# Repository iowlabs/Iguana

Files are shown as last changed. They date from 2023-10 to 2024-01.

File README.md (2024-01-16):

# iow Labs Iguana

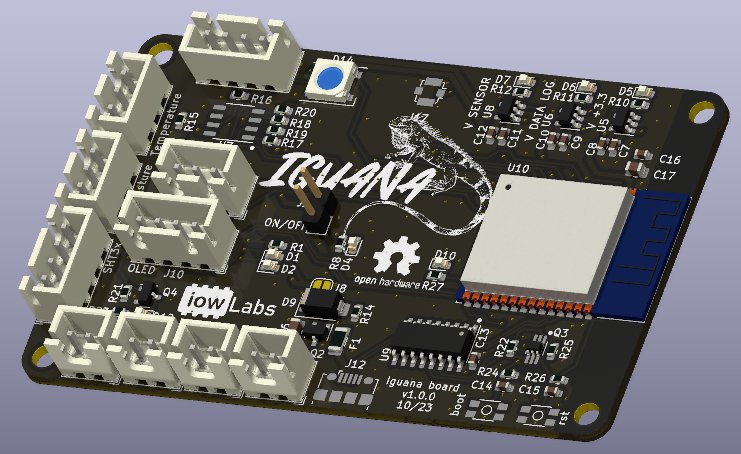
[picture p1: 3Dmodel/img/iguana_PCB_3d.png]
Foto real


Iguana is a LoRa sensor for Smart Cities. It is an instrument designed to monitor soil temperature and humidity in real time. It is a low-cost device designed to address a wide range of scenarios. It has connectivity to different types of wireless networks (LoRa, Bt, BLE, Wifi, RF), adapting to a large number of IoT applications.

The PCB was designed with various scenarios in mind that contemplate the common needs associated with automatic irrigation, smart agriculture and soil quality monitoring. Both at the level of domestic applications and at the level of industrial applications.

The sensor considers compatibility with the following sensors:

- Soil moisture sensor ds18b20
- soil temperature sensor.
- Humidity and ambient temperature sensor.

It also has a  on board driver for a little water pump, a LoRa module, an RTC module and an SD socket for datalogger functions and an OLED screen to display instant information. Another interesting attribute is that it has an RS485 converter, which allows the iguana device to be integrated with industrial sensors for monitoring soil humidity and quality that are usually compatible with ModBus RS485 protocols.

**IoT**,**LoRa**, **Environmental measurement**, **Soil mositure**, **datalogger**, **MODBUS RS485**.

### OSHW LICENSES

 OSL  

## Hardware description

The PCB was designed in KiCad7 stable realease and additional components used can be found in the official [iowLabs](https://github.com/iowlabs/KiCad_Lib) library.

It has an ESP32 microcontroller, an RF95 module to integrate into LoRa and LoRaWAN network solutions. It has an RTC RV8803 and a micro SD card connector necessary to implement data logger functions.
It additionally has a "max485" module to integrate probes for quality monitoring of industrial soils based on MODBUS RS485 communication protocol.

A simple NPN-based controller allows you to integrate small water pumps to implement automatic and remote irrigation control functionalities.

An OLED display and RGB LED let you see real-time information from the sensors.

It also has a charging module for lipo batteries based on the integrated TP4056 and a charging protection circuit. Integration with solar panel based applications can be easily achieved.

To manage the power of the circuit, an MT3608 DC DC converter and a set of LDO regulators are used that power the digital electronics, the sensors and the data logger independently. The regulators that power the units can be disabled via firmware to implement low-power features.

### Dependencies
The board is based on an ESP32 microcontroller.

- USB communication through IC CH340
- Lora rfm95 module.
- microSD socket.
- RV8803 RTC module.
- max485 for RS485 communication.
- On board pump driver with a NPN 2N3904.
- On board battery charger compatible with 3.7V lipo bateries, based on TP4056.
- ws2812 RGB LED
- OLED display

### Schematic

Detalle del esquemático de la placa phecda

### Layout
The layout is a 2 layers 8x5cm pcb.

| Top view | Bottom view |
| --- | --- |
| front view of the pcb form kicad|back view of the pcb form kicad|

### BOM

The bill of materials with respective references to the LCSC part numbers of the iguana PCB components can be found in the following [link](hardware/output_files/Iguana_V1_BOM.csv).

Below is a list of the components for the probes and sensors that complement the iguana device to implement all its functionalities. The prices provided and the links are for reference only.

|  component 	| ref price 	| description 	| Link 		|
| --- 	| --- 	| --- | ---	|
| Soil mositure sensor| | 	Low cost, soil moisture capacitive sensor	|			|
| Soil temperature sensor | | Sensor ds18b20 | |
| Sensor de humedad y temperatura ambiente | | SHT31 - case outdoor IP68 | |
| Sensor de Temperatura y humedad de suelo industrial | | Sensor MODBUS 485 capacitivo, de humedad y temperatura de suelo. | |
| Pantalla OLED |  | 128x64 1.3'' | |
| Batería LiPo  |  | Batería lipo 3.7V 2500mAh.Tamaño menor a 65x55cm.  | |
| Tarjeta microSD | | 16GB | |
| Batería 2012 	| | Batería 3.3V CR2012 | |

## 3D Model

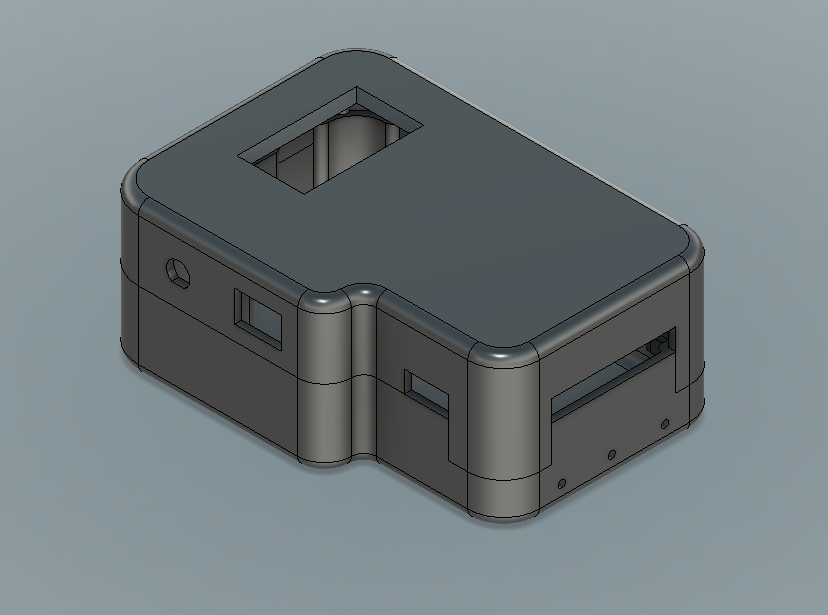
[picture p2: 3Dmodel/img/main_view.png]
Enclousure diseñado para Iguana


Render 3D de la placa Iguana

The design allows the integration of the OLED and RGB LED display to monitor the status of the device and read the latest value from the sensors. it leaves exposed the connectors for the probes, the SMA connector for the LoRa antenna, and a switch to turn the device on and off.

| Cover | Base |
| --- | --- |
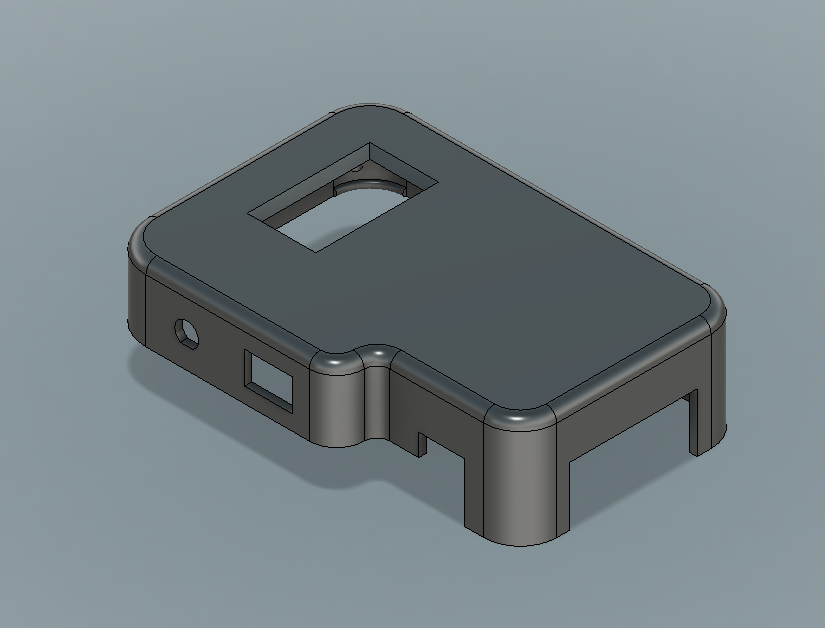
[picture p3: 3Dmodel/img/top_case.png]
componente superior del case
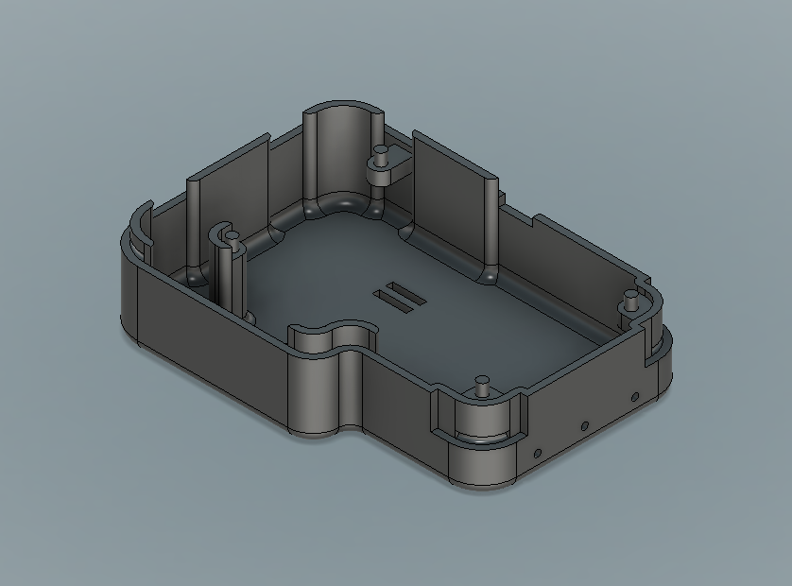
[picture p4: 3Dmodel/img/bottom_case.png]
componente inferior del case
| ||

Design view files:

- [plans](Iguna_case_V2.pdf)

The device considers a 65x54 cm 3.7V lipo battery for power. This battery can be charged externally through the USB connector or through the charging input connector.

Editable files and display plans can be found in [directorio](3Dmodel/Source_files).

The PCB design allows it to fit commercial project enclosures with IP65 standards or higher for outdoor or harsh weather applications.

## Firmware

The developed firmware represents a collection of libraries and drivers for the board's dependencies.

This collection of useful functions is implemented in the iowIguana library. However, due to the flexibility of the design, it is possible to load a wide variety of code based on other supported libraries.

The firmware was developed using PlatformIO; however, usage examples were generated for [Arduino IDE] (https://www.arduino.cc/en/software).

|  Folder  | Description |
| ---| --- |
| [firmware/iguana_project](firmware/iguana_project) | The complete project compiled in its last version.|
| [firmware/examples](firmware/examples) | Arduino compatible example codes .|
| [firmware/src](firmware/src) | The source files of the library made for iguana.|

### Used libraries
Except for the uSD_iow library which is available in the official iowlabs repository, all other libraries used are available from the official Arduino and PlatformIO library manager.

- RTC 			: sparkfun/SparkFun Qwiic RTC RV8803 Arduino Library @ ^1.2.8
- Temperature sensor	: paulstoffregen/OneWire@^2.3.7
- Temperature sensor 	: milesburton/DallasTemperature@^3.11.0
- Temperature and humidity sensor : adafruit/Adafruit SHT31 Library@^2.2.2
- Temperature and humidity sensor : adafruit/Adafruit BusIO@^1.14.3
- Temperature and humidity sensor : adafruit/Adafruit Unified Sensor@^1.1.13
- ArduinoJson	:	bblanchon/ArduinoJson@^6.21.3
- OLED			: adafruit/Adafruit SH110X @ ^2.1.8
- OLED 			: adafruit/Adafruit GFX Library @ ^1.11.5
- fastLED		: fastled/FastLED@^3.6.0
- LoRa 			: sandeepmistry/LoRa @ ^0.8.0
- MQTT               : knolleary/PubSubClient@^2.8

### Available examples

| File | Description |
|---|---|
| simple_version.ino  | Collect the data from the soil moisture and the soil temperature sensors, and displays it on the screen. Print the collected data in json format through the serial monitor. |
| low_energy_version.ino |  Adds a low-power mode to the simple_version code |
| lora_version.ino | Activate the LoRa module and send a message in json format. |
| mqtt_version.ino | This is an example of reading the data and sending it via MQTT to a pre-established broker.|

### Available functions

- uint8_t begin(void);
- void readSoilTemperature(void);
- void readSoilMoisture(void);
- void readSTH(void);
- void readRS485(void);
- void readSensors(void);
- String pubData(void);
- void activateSensors(uint8_t sens);
- void activateLoRa(void);
- void activateAll(void);
- void iowLogo(void);
- void showLogo(void);
- void showStatus(void);
- void showData(long time_interval);
- void saveData(void);
- void moistureCal(uint8_t val);
- void temperatureCal(uint8_t val);

## OTA UPDATE Disclaimer
- Iguana ahora es capaz de tener actualizaciones Http mediante OTA
- En la carpeta test se encuentra el archivo "OTA_update_mqtt.cpp"
- Robusto ante corte de energía durante actualización
- Existía un bug cuando se cortaba el wifi del dispositivo en medio de una actualización. Se levantaba un error de la librería WiFiClientSecurity en el archivo ssl_client.cpp
- Solución a bug: Se modifica el archivo ssl_client.cpp de forma que a penas se levante el error (linea 37) se haga ESP.restart(). Con esto OTA es robusto ante cualquier fallo testeado.
- Para que todo se encuentre en el repo, se descargaron los archivos .cpp y .h de la librería WiFiClientSecurity y se cargaron en la carpeta libs del proyecto. Esto con el fin de que el arreglo lo pueda pullear cualquiera que tome este código.

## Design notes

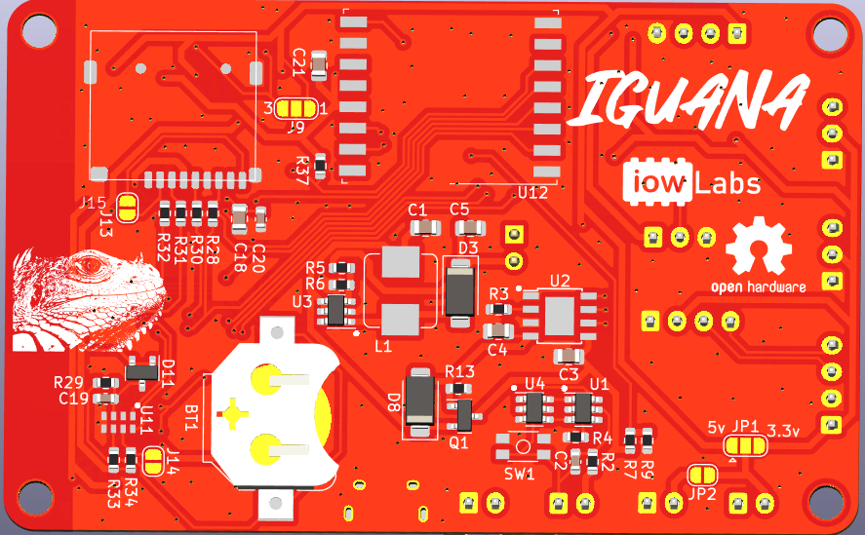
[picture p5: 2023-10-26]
hardware/output_files/Iguana_V1_botom.png

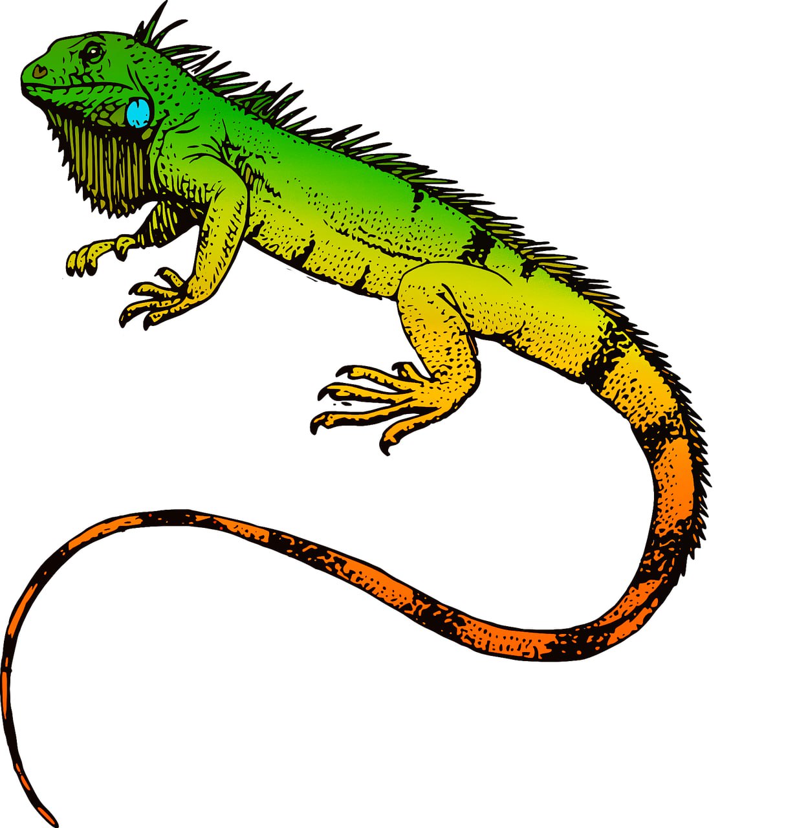
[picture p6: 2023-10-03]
hardware/fotos/photo_iguana_free.jpg

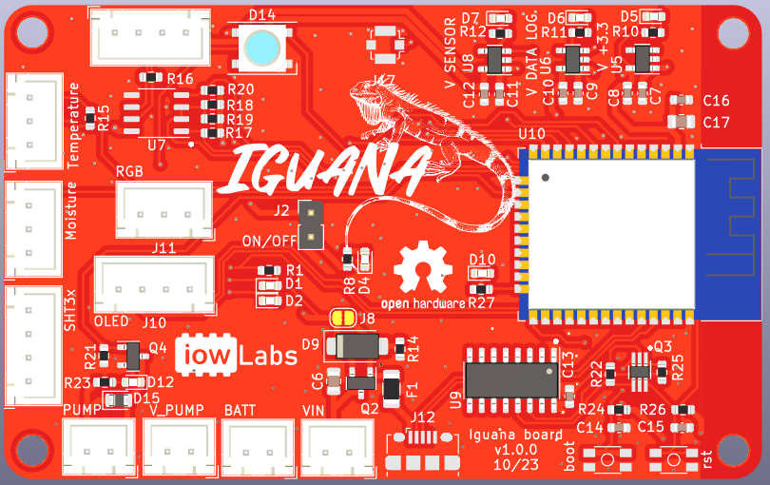
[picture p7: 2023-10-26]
hardware/output_files/Iguana_V1_top.png

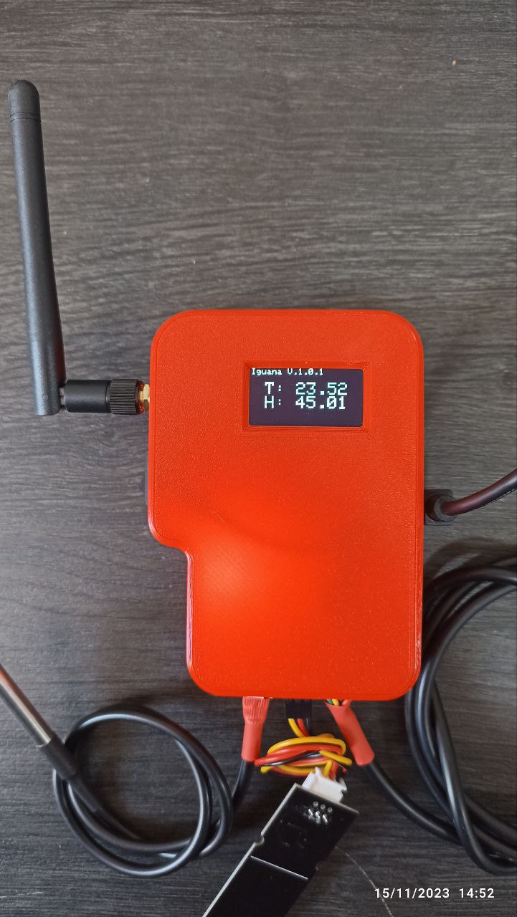
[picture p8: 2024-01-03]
3Dmodel/img/iguana_real.jpg

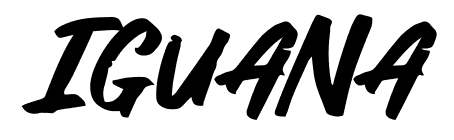
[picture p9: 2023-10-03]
hardware/fotos/logo.png

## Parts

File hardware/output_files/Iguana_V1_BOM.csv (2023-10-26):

Item | Reference(s) | Qty | Value | Footprint | Supplier | Supplier part number
Battery holder | BT1 | 1 | Battery_Cell | Battery:BatteryHolder_Keystone_3000_1x12mm | LCSC | C964819
CAP ceramic | C1, C5 | 2 | 22u | Capacitor_SMD:C_0805_2012Metric | LCSC
CAP ceramic | C2, C13, C14, C15, C16, C20 | 6 | 100n | Capacitor_SMD:C_0603_1608Metric | LCSC | C1591
CAP ceramic | C3, C4, C17, C18 | 4 | 10u | Capacitor_SMD:C_0805_2012Metric | LCSC | C386019
CAP ceramic | C6, C21 | 2 | 4.7u | Capacitor_SMD:C_0805_2012Metric | LCSC | C98192
CAP ceramic | C7, C8, C9, C10, C11, C12 | 6 | 1u | Capacitor_SMD:C_0603_1608Metric | LCSC | C5673
CAP ceramic | C19 | 1 | 10n | Capacitor_SMD:C_0603_1608Metric | LCSC | C100042
LED SMD BLUE 0603 |  |  |  | LED_SMD:LED_0603_1608Metric | LCSC
LED SMD BLUE 0603 |  |  |  | LED_SMD:LED_0603_1608Metric | LCSC
LED SMD BLUE 0603 | D1, D2, D4, D5, D6, D7, D10, D12 | 8 |  | LED_SMD:LED_0603_1608Metric | LCSC | C99290
Diode schottky | D3, D8, D9 | 3 |  | Diode_SMD:D_SMA | LCSC | C85098
Diode BAS70-05 | D11 | 1 |  | Package_TO_SOT_SMD:SOT-23 | LCSC | C131857
RGB SMD LED WS2812B | D14 | 1 |  | LED_SMD:LED_WS2812B_PLCC4_5.0x5.0mm_P3.2mm | LCSC
Generic diode CD4148W | D15 | 1 |  | Diode_SMD:D_0805_2012Metric | LCSC
Fuse | F1 | 1 |  | Fuse:Fuse_1206_3216Metric | LCSC | C553921
Header male 2x1 p2.54 | J2 | 1 |  | Connector_PinHeader_2.54mm:PinHeader_1x02_P2.54mm_Vertical | LCSC | C180247
Connector JST XH 2x1 p2.5 | J1,J3, J18, J19 | 4 |  | Connector_JST:JST_XH_B2B-XH-A_1x02_P2.50mm_Vertical | LCSC
Connector JST XH 3x1 p2.5 | J4,J5,J11 | 3 |  | Connector_JST:JST_XH_B3B-XH-A_1x03_P2.50mm_Vertical | LCSC
Connector JST XH 4x1 p2.5 | J6,J7,J10 | 1 |  | Connector_JST:JST_XH_B4B-XH-A_1x04_P2.50mm_Vertical | LCSC | C37815
Solder Jumper | J8,J13,JP1 | 3 |  | Jumper:SolderJumper-2_P1.3mm_Open_RoundedPad1.0x1.5mm
Solder Jumper | J9,J14,JP2 | 3 |  | Jumper:SolderJumper-3_P1.3mm_Open_RoundedPad1.0x1.5mm_NumberLabels
USB micro b | J12 | 1 |  | Connector_USB:USB_Micro-B_Amphenol_10118194_Horizontal | LCSC | C132563
Micro SD holder push push | J15 | 1 |  | IoWLabsConnectors:microSD_push_push | LCSC
Connector UFL SMD | J17 | 1 |  | Connector_Coaxial:U.FL_Molex_MCRF_73412-0110_Vertical | LCSC | C88374
Inductance SMD | L1 | 1 | 22u | Inductor_SMD:L_Bourns_SRP7028A_7.3x6.6mm | LCSC
PMOS transistor | Q1, Q2 | 2 |  | Package_TO_SOT_SMD:SOT-23 | LCSC | C518789
LMBT3904 Dual NPN transistor | Q3 | 1 |  | Package_TO_SOT_SMD:SOT-363_SC-70-6_Handsoldering | LCSC | C131781
PMOS transistor BSS138 | Q4 | 1 |  | Package_TO_SOT_SMD:SOT-23 | LCSC | C400505
RES SMD | R1, R10, R11, R12, R23,R4, R6 | 7 | 1k | Resistor_SMD:R_0603_1608Metric | LCSC
RES SMD | R2 | 1 | 100 | Resistor_SMD:R_0603_1608Metric | LCSC
RES SMD | R3 | 1 | 1K2 | Resistor_SMD:R_0603_1608Metric | LCSC
RES SMD | R5 | 1 | 7K5 | Resistor_SMD:R_0603_1608Metric | LCSC
RES SMD | R7 | 1 | 12K | Resistor_SMD:R_0603_1608Metric | LCSC
RES SMD | R8 | 1 | 470 | Resistor_SMD:R_0603_1608Metric | LCSC
RES SMD | R9 | 1 | 30K | Resistor_SMD:R_0603_1608Metric | LCSC
RES SMD | R15 | 1 | 4.7K | Resistor_SMD:R_0603_1608Metric | LCSC | C99782
RES SMD | R16 | 1 | 120 | Resistor_SMD:R_0603_1608Metric | LCSC
RES SMD | R17, R18, R19, R20, R37,R13, R14, R22, R24, R25, R26,21 | 12 | 10k | Resistor_SMD:R_0603_1608Metric | LCSC | C25804
RES SMD | R27 | 1 | 330 | Resistor_SMD:R_0603_1608Metric | LCSC | C105881
RES SMD | R28, R29, R30, R31, R32 | 5 | 3.3k | Resistor_SMD:R_0603_1608Metric | LCSC | C25995
RES SMD | R33, R34 | 2 | 100k | Resistor_SMD:R_0603_1608Metric | LCSC | C2907088
Switch button smd | SW1, SW2, SW3 | 3 |  | IoWLabs:SMD_SWITCH | LCSC | C128941
53 | U1 | 1 | DW01 | Package_TO_SOT_SMD:SOT-23-6 | LCSC
54 | U2 | 1 | TP4056 | IoWLabs:TP4056_SOP-8-PP | LCSC
55 | U3 | 1 | MT3608 | Package_TO_SOT_SMD:SOT-23-6 | LCSC
56 | U4 | 1 | FS8205A | Package_TO_SOT_SMD:SOT-23-6 | LCSC
LDO 3.3V AP2112K-3.3 | U5, U6, U8 | 3 |  | Package_TO_SOT_SMD:SOT-23-5 | LCSC | C150742
58 | U7 | 1 | MAX3485 | Package_SO:SOP-8_3.9x4.9mm_P1.27mm | LCSC
CH340 usb to serial | U9 | 1 | CH340C | Package_SO:SOIC-16_3.9x9.9mm_P1.27mm | LCSC | C84681
ESP32 | U10 | 1 |  | RF_Module:ESP32-WROOM-32 | LCSC | C473012
RTC RV-8803 | U11 | 1 | RV-8803 | IoWLabs:SON-8 | LCSC | C2846926
LORA RFM95W-915S2 module 915hz | U12 | 1 | RFM95W-915S2 | RF_Module:HOPERF_RFM69HW | LCSC | C2844473

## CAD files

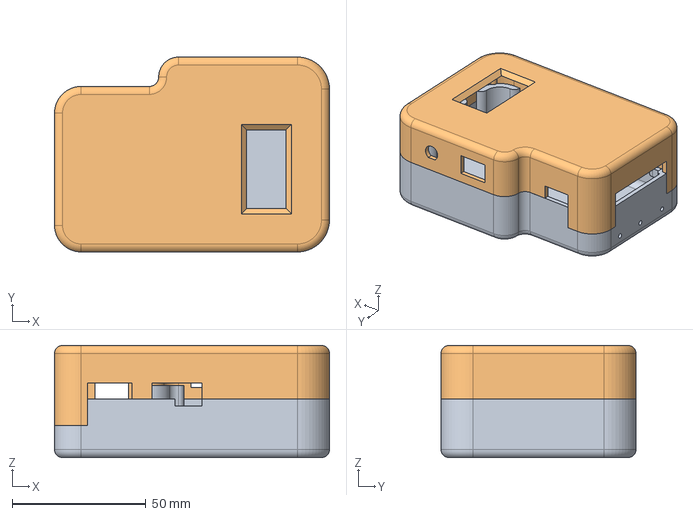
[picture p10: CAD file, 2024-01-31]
3Dmodel/Source_files/V3/Iguana_Case_Final v3.step
103.0 x 73.0 x 42.0 mm

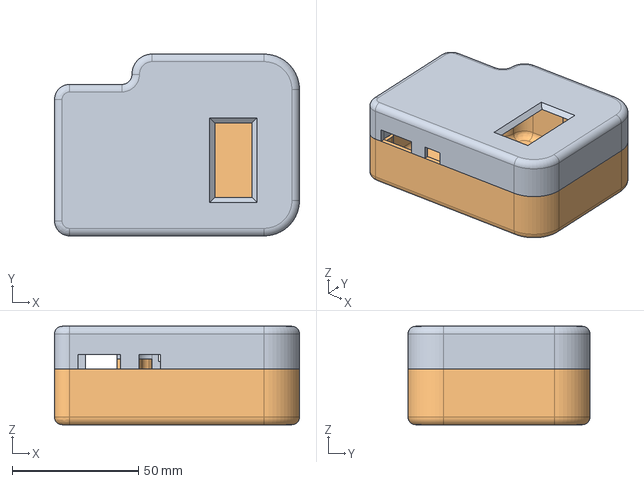
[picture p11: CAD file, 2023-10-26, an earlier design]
3Dmodel/Source_files/V1/Iguana_Case_V1.step
97.0 x 72.0 x 39.0 mm

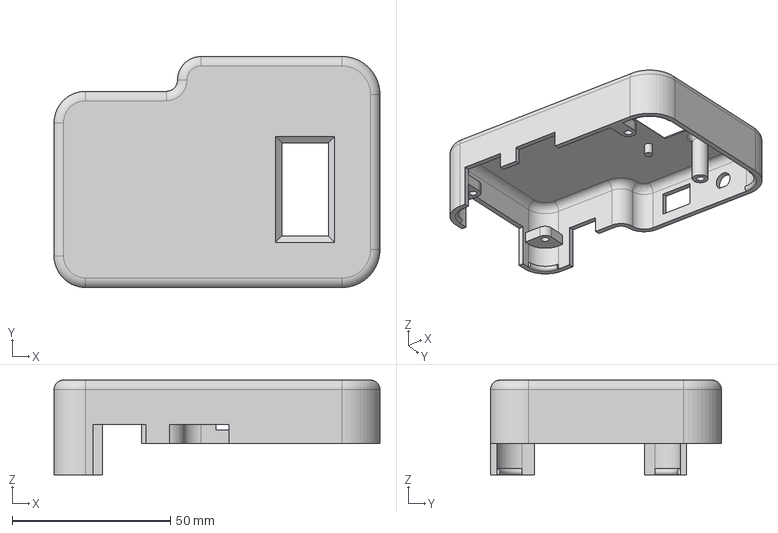
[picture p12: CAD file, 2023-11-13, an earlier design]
3Dmodel/Source_files/V2/Iguana_Case_Final v2.step
103.0 x 73.0 x 30.0 mm

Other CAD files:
3Dmodel/Source_files/V1/Iguana_Case_V1.3mf
3Dmodel/Source_files/V1/Iguana_Case_V1.stl
3Dmodel/Source_files/V2/Iguana_Case_Final v2.f3z
3Dmodel/Source_files/V2/Iguana_Case_Final v2.stl
3Dmodel/Source_files/V3/Iguana_Case_V1.f3z

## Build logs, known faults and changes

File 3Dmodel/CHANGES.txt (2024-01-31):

- V1:
	- Uses magnets, has to be stopped at the 3Dprint
	- Fitting good, dissasembles easy
	- Screen has 1 to 2mm vertical misalignment.

- V2:
	- Discarded magnets, uses tab and slot union, more difficult to close, more realiable.
	- Construction file is simpler, construction was made more efficiently.
	- Screen fits better.

- V3:
	- Increased girth of top tongues, because of structural issue.

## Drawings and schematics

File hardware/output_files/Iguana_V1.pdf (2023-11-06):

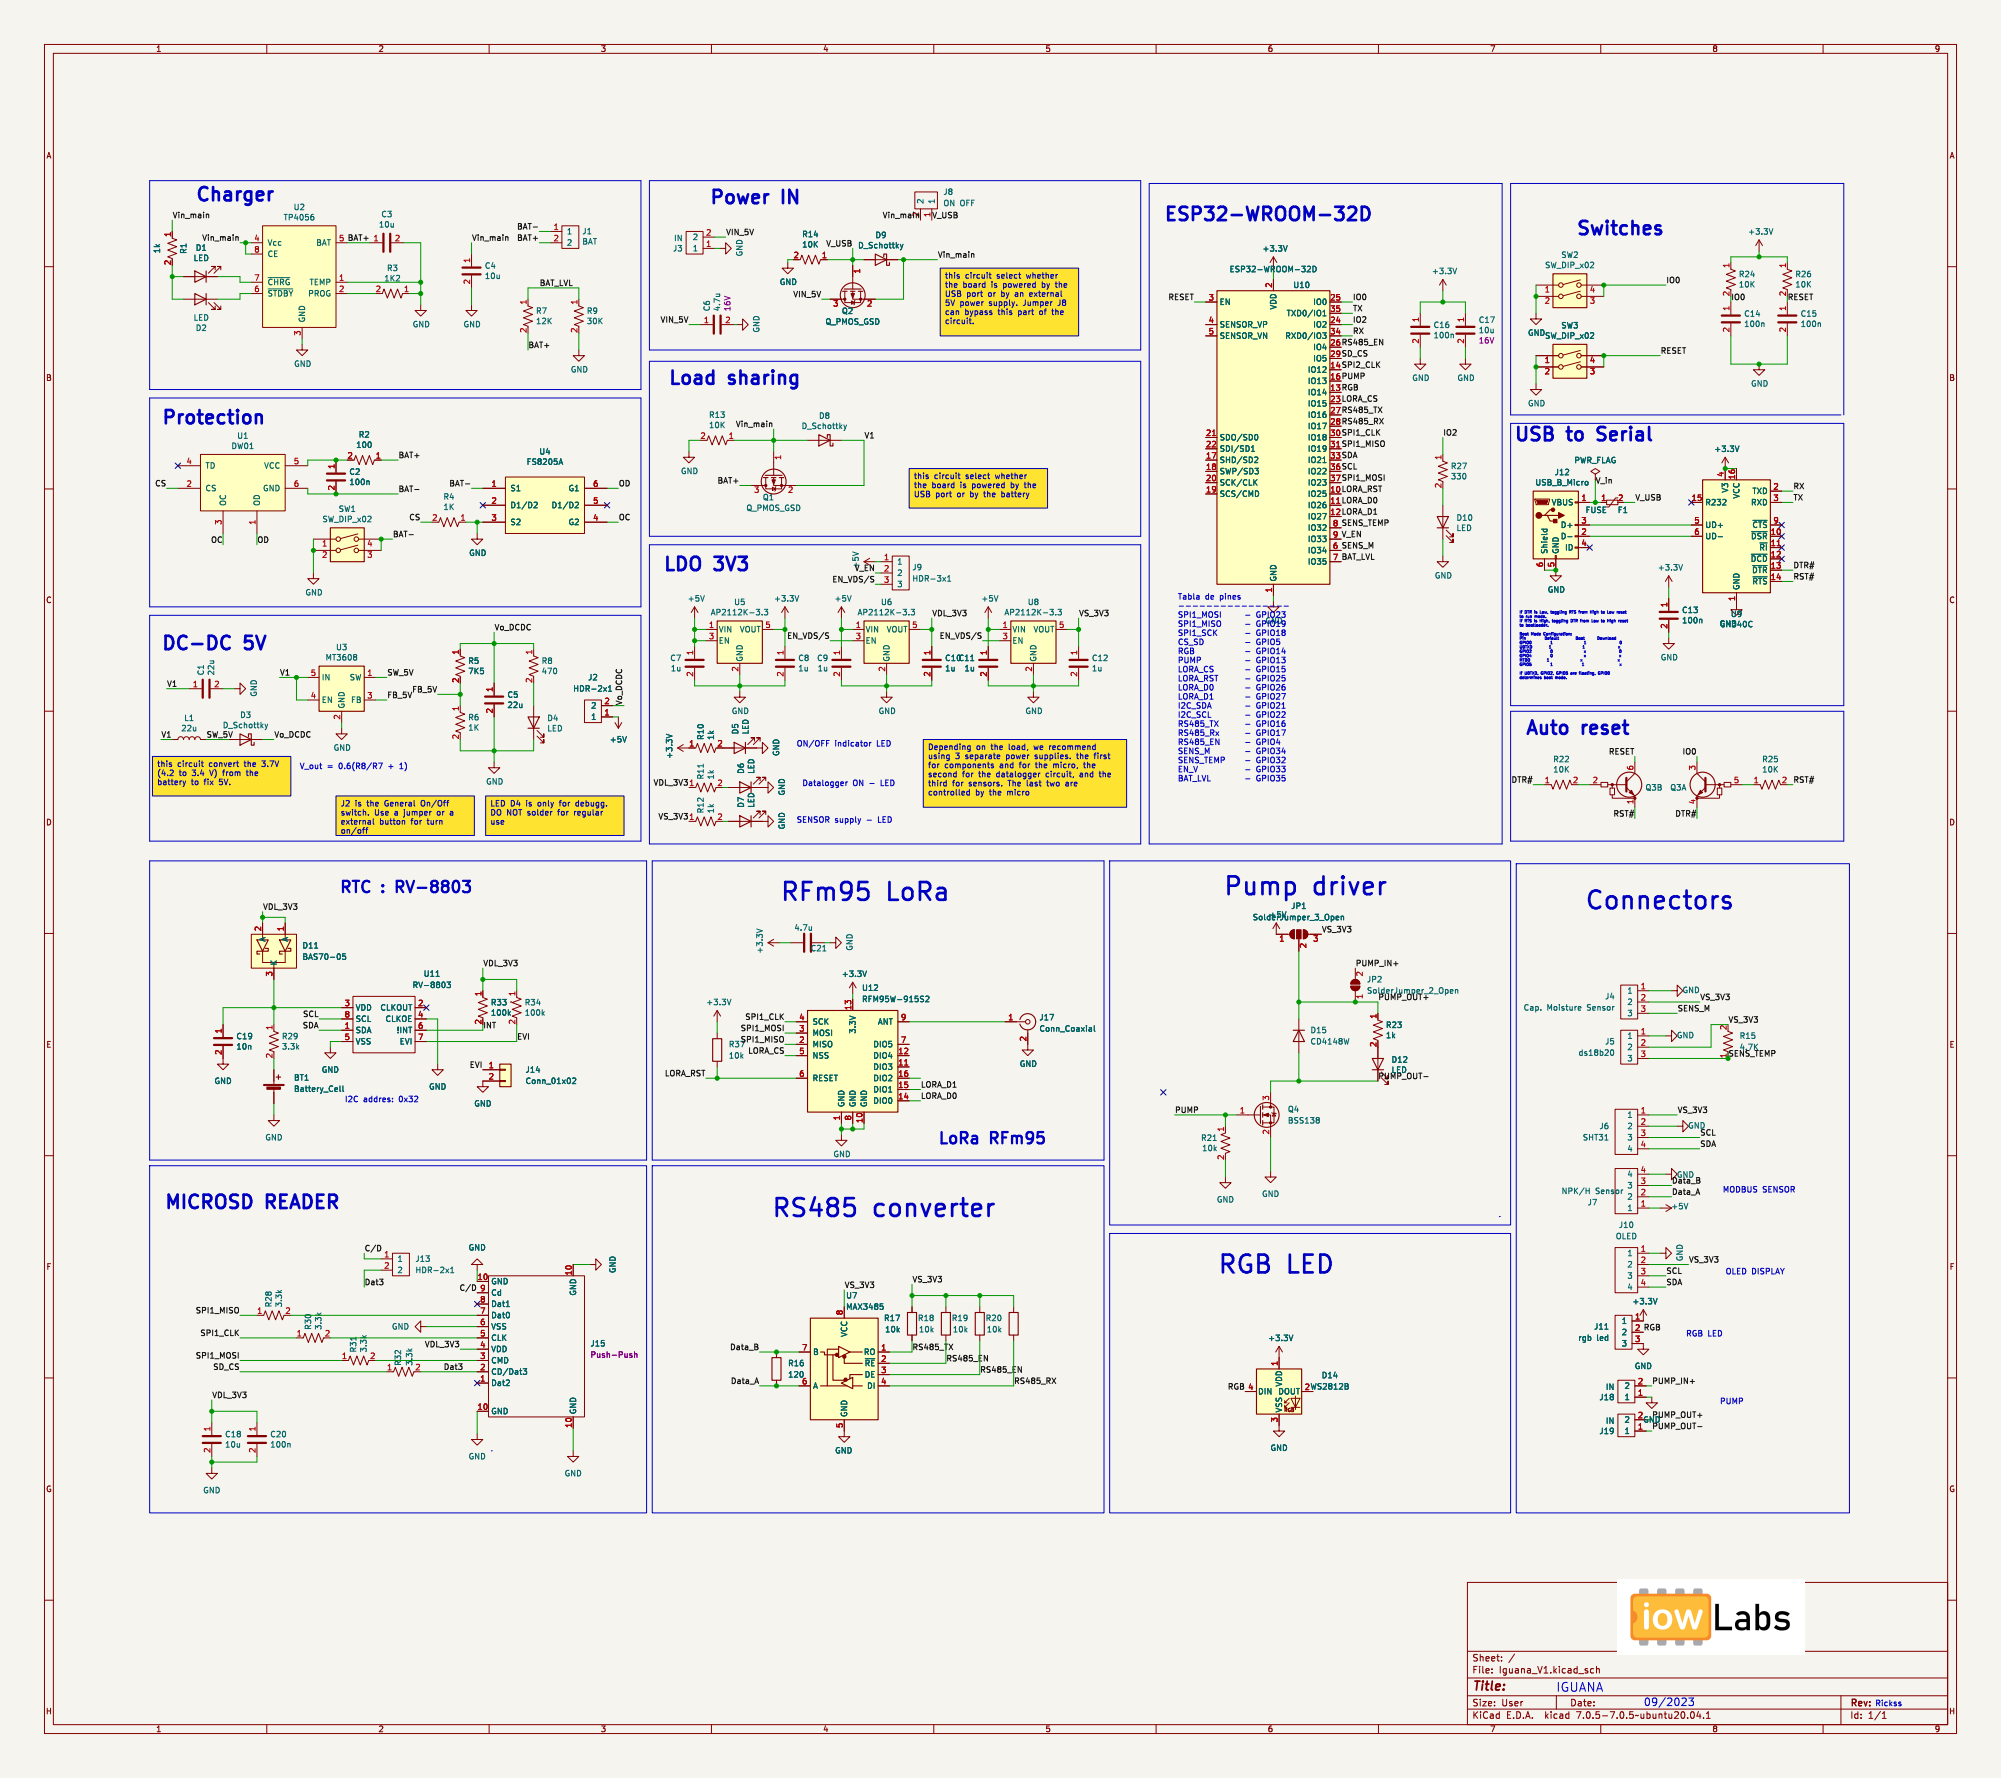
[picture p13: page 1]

3 Vcc 4 BAT 5 ~{STDBY} 6 ~{CHRG} 7 CE 8 U2 TP4056

the board is powered by the USB port or by an external 5V power supply. Jumper J8

2 SCK/CLK 20 SDO/SD0 21 SDI/SD1 22
RESET RESET DTR#

can bypass this part of the
circuit.

the board is powered by the USB port or by the battery

1 ~{DSR} 10 ~{RI} 11 ~{DCD} 12 ~{DTR} 13 ~{RTS} 14 R232

Depending on the load, we recommend
third for sensors. The last two are

J2 is the General On/Off switch. Use a jumper or a

RGB LED RTC : RV-8803

1 GND 10 DIO3 11 DIO4 12 3.3V 13 DIO0 14 DIO1 15 DIO2 16 MISO 2 MOSI 3 SCK 4 NSS 5 RESET 6 DIO5 7 GND

U7 MAX3485 RO 1 ~{RE}2 DE 3 DI 4 GND

10k RO 1 ~{RE}2 DE 3 DI 4 GND

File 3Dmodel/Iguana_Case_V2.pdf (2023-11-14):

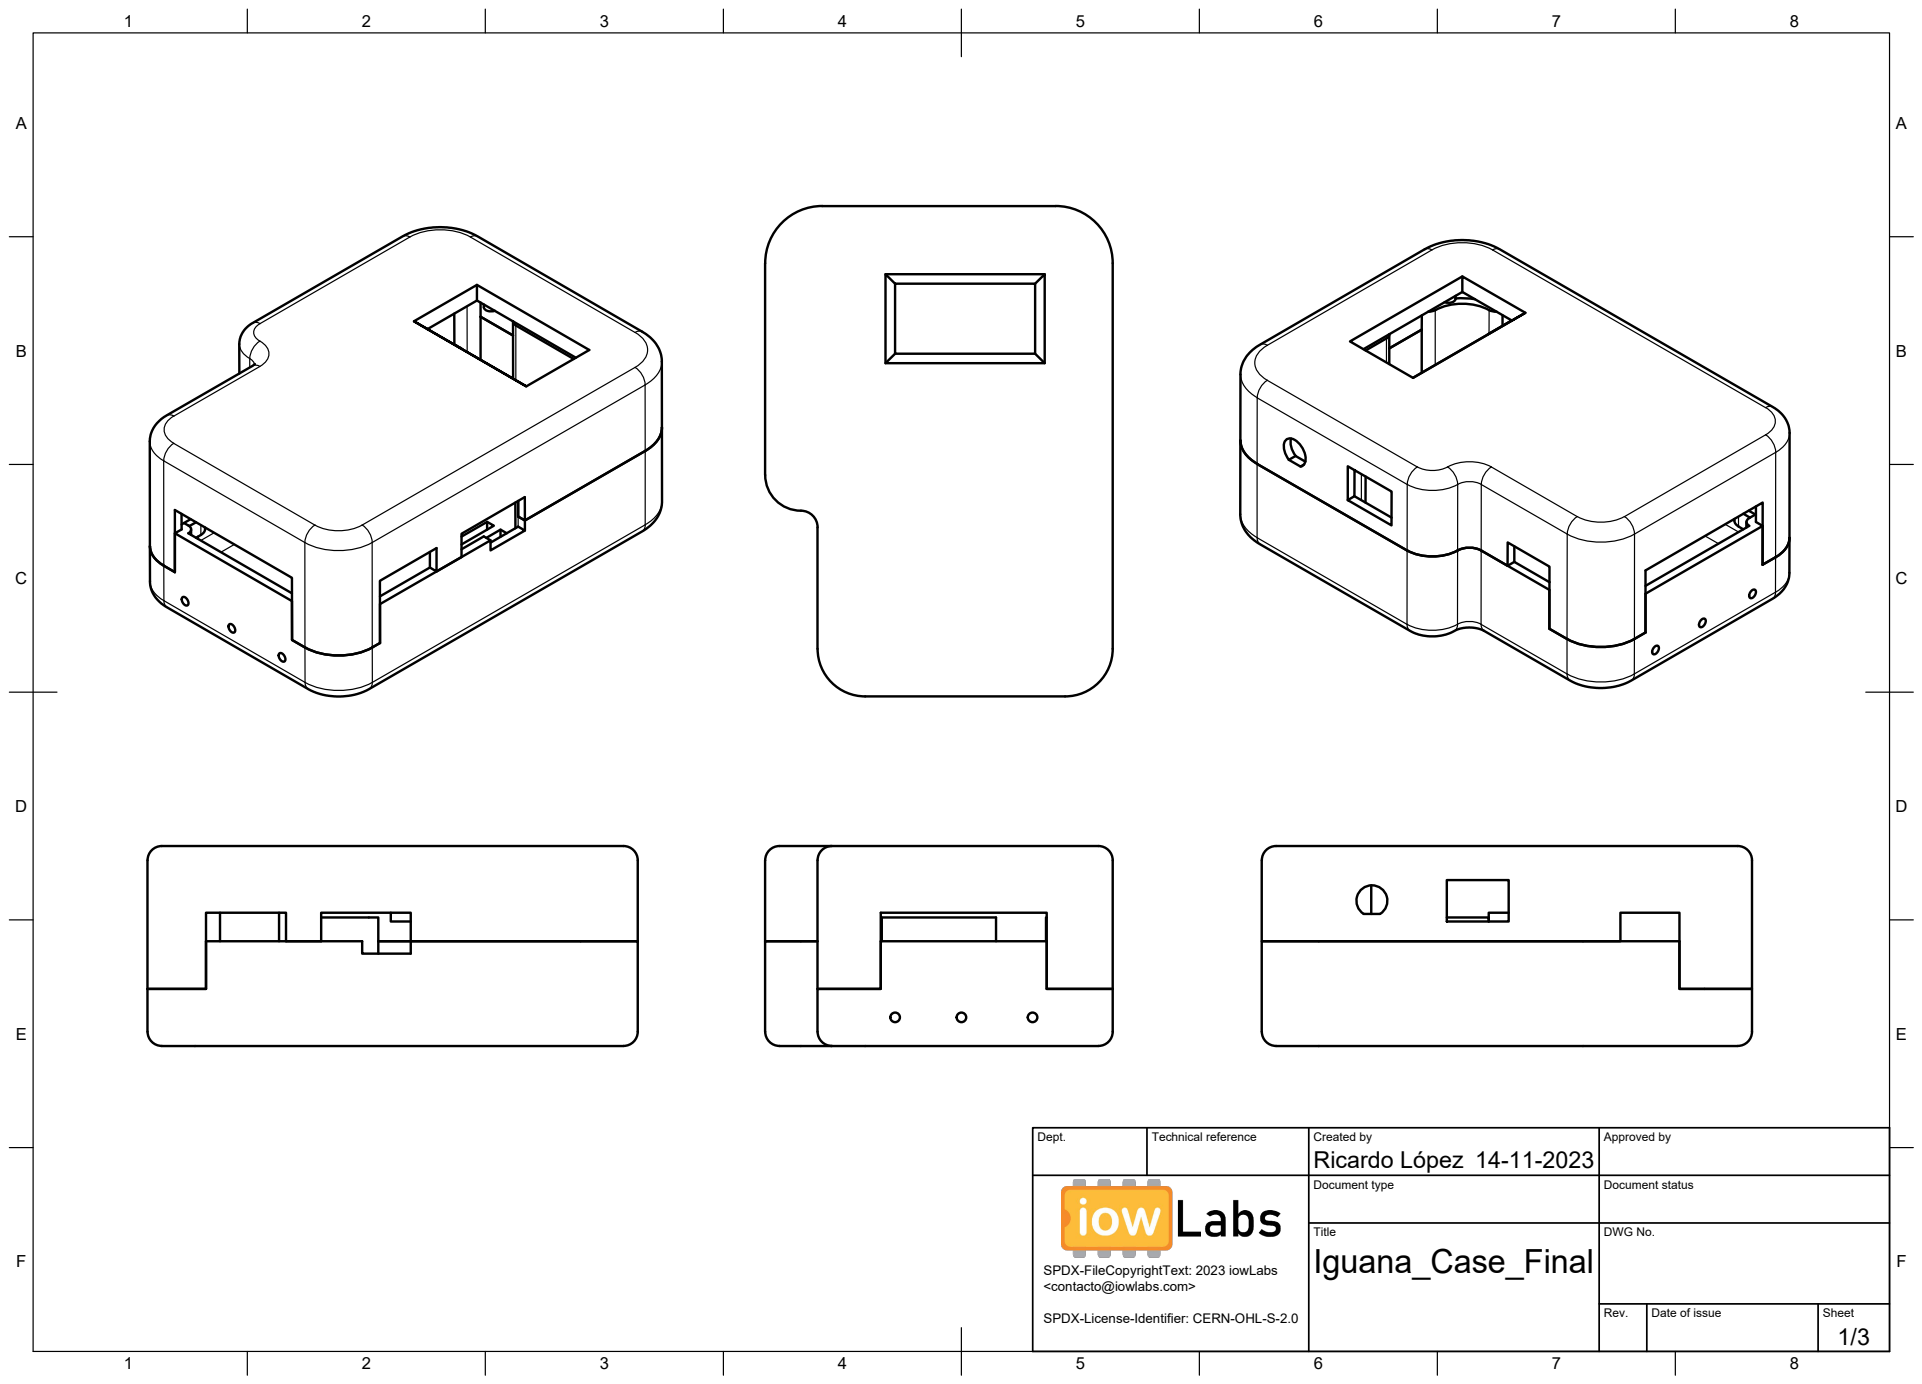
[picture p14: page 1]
Title; DWG No.; Rev.; Date of issue; Sheet

Dept. | Technical reference | Created by Ricardo López 14-11-2023 | Approved by

Document type | Document status

SPDX-FileCopyrightText: 2023 iowLabs
<contacto@iowlabs.com>

SPDX-License-Identifier: CERN-OHL-S-2.0

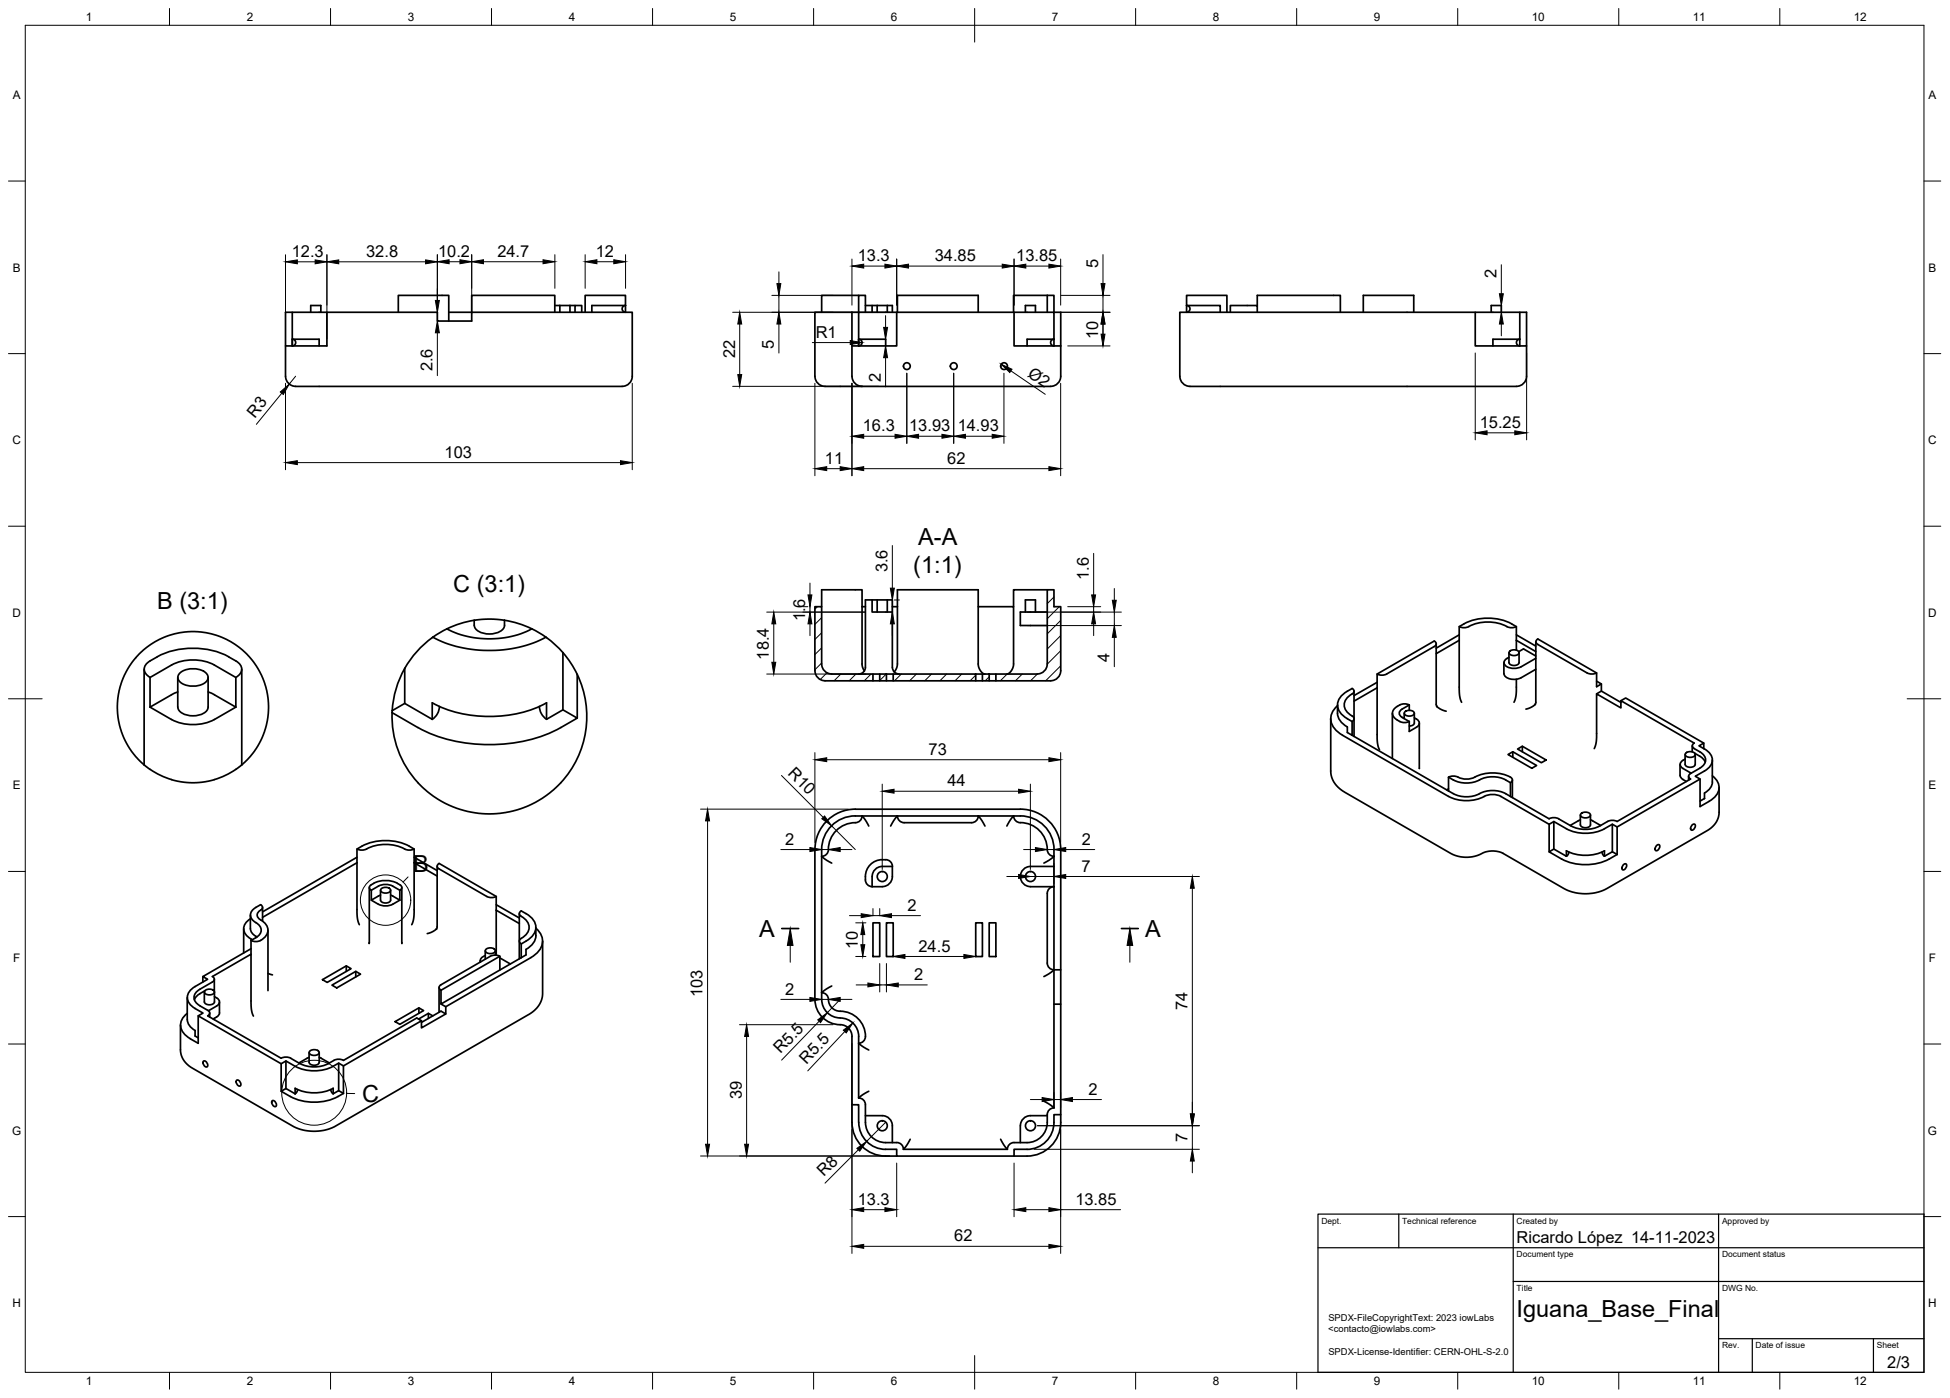
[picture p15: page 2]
Ricardo López 103

Dept. | Technical reference | Created by 14-11-2023 | Approved by

SPDX-FileCopyrightText: 2023 iowLabs | | Document type | Document status

Title Iguana_Base_Final | DWG No.

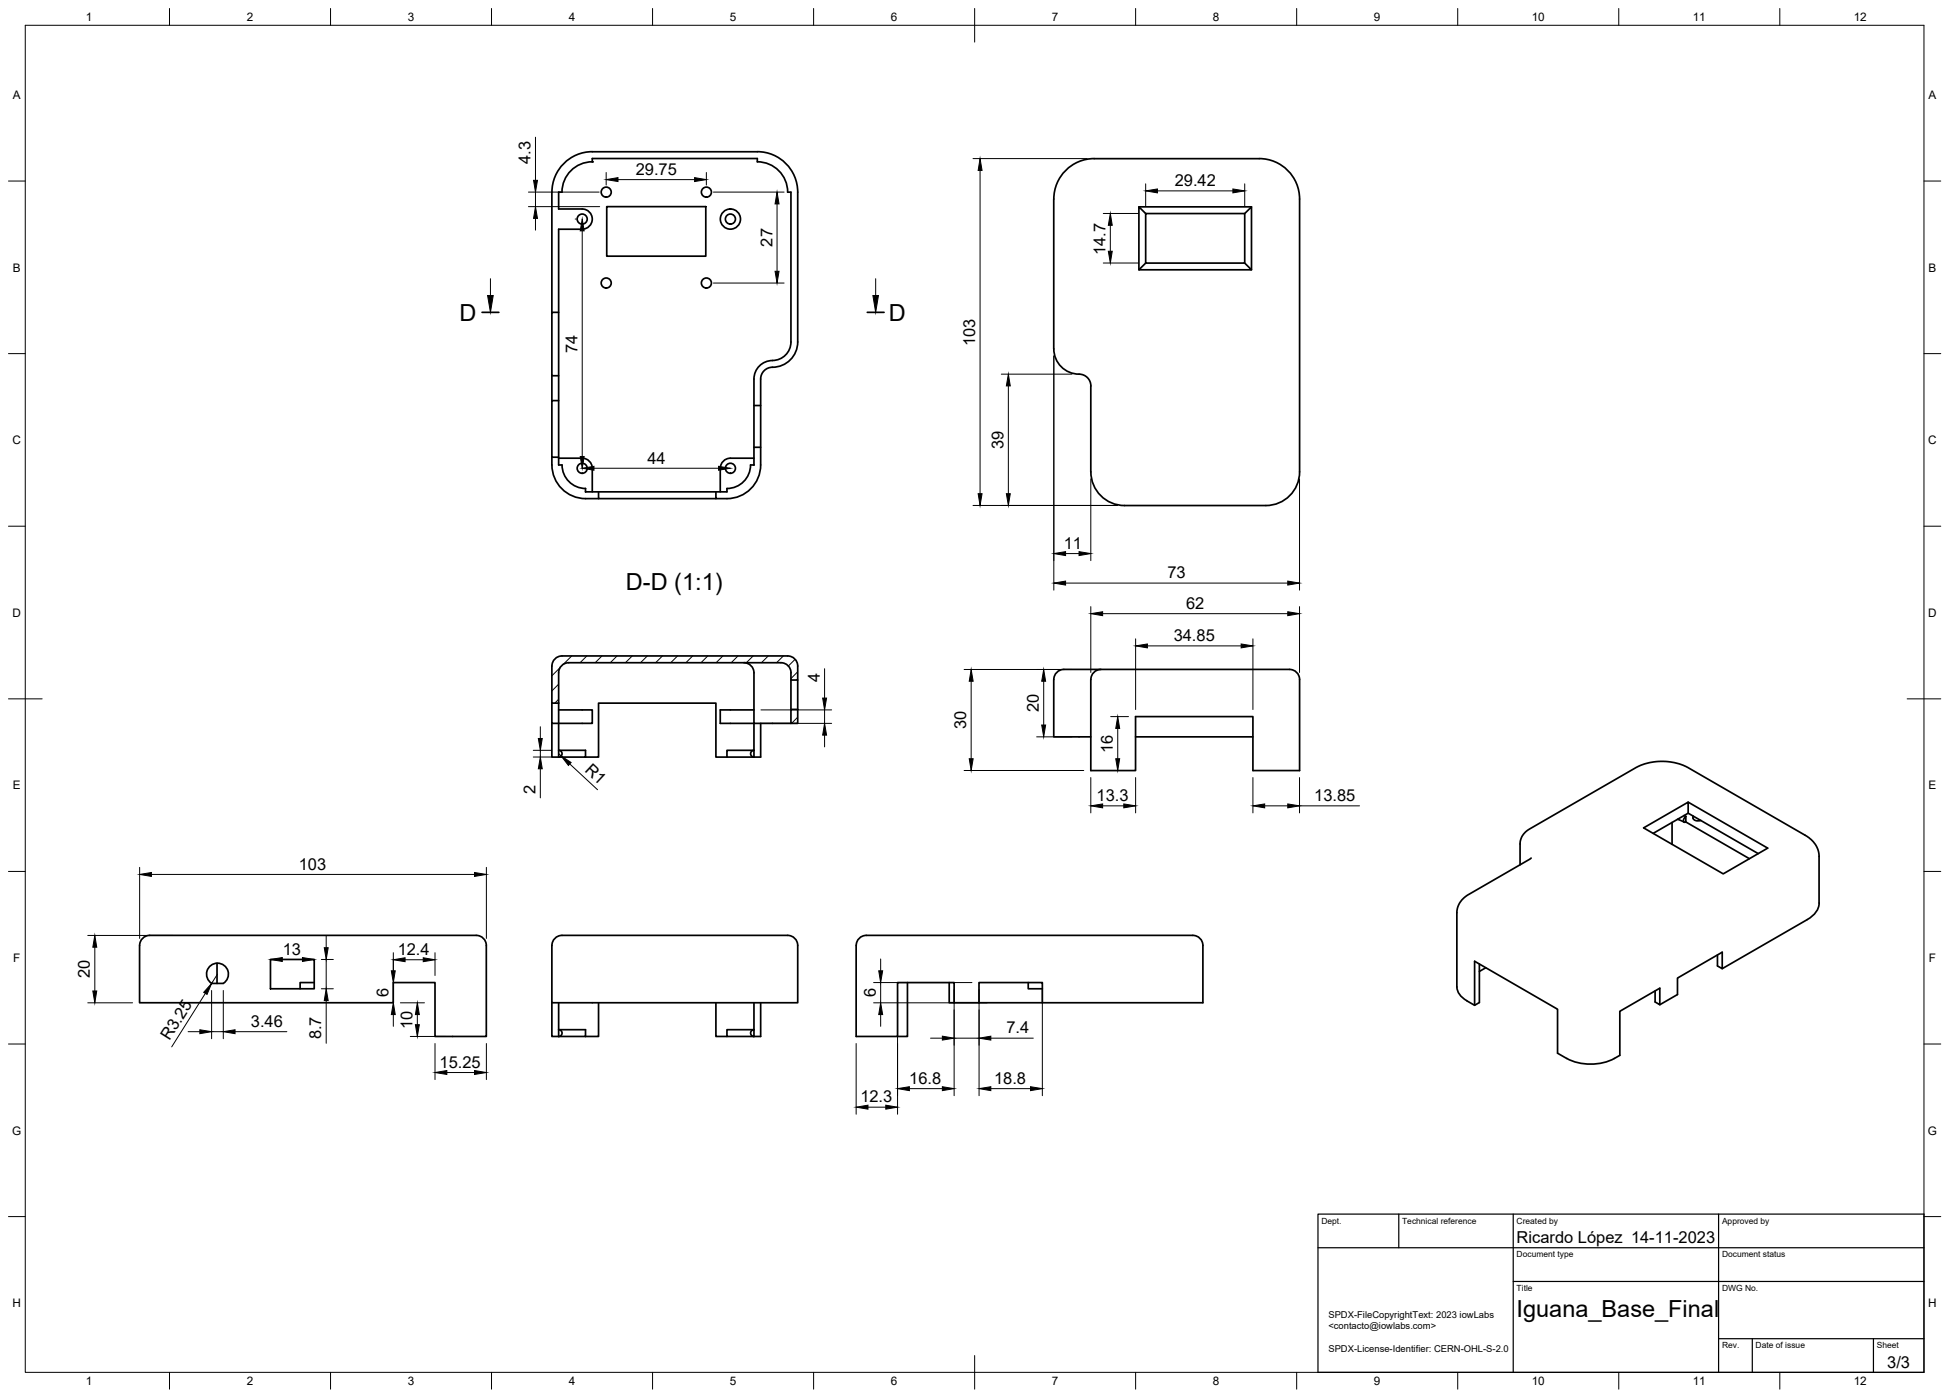
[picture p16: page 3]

Dept. | Technical reference | Created by Ricardo López 14-11-2023 | Approved by

SPDX-FileCopyrightText: 2023 iowLabs | | Document type | Document status

Title Iguana_Base_Final | DWG No.

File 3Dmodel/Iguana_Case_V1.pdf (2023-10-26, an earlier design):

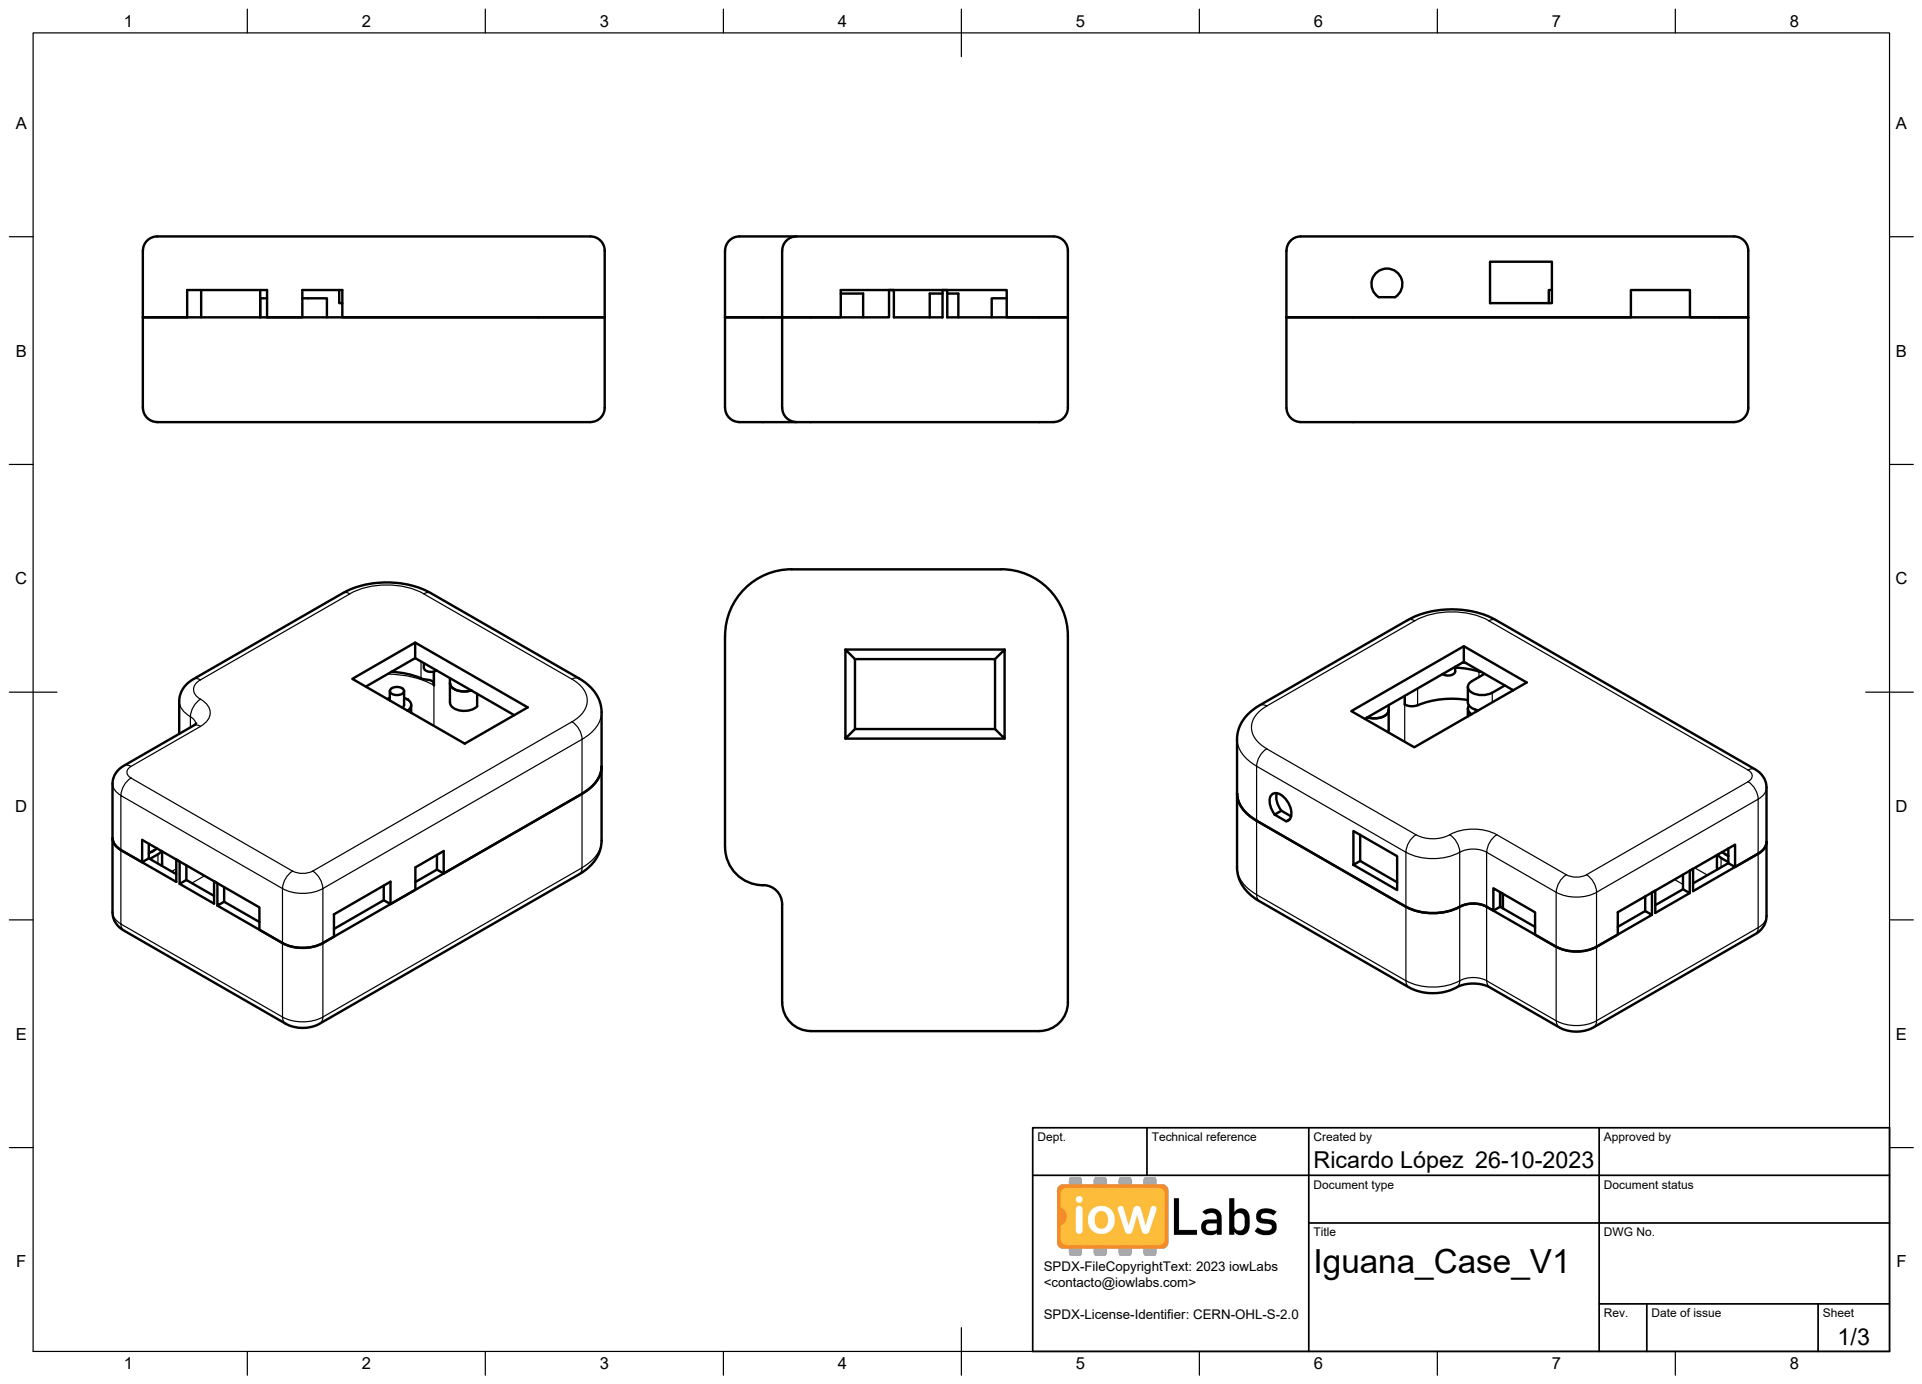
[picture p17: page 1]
Title; DWG No.; Rev.; Date of issue; Sheet

Dept. | Technical reference | Created by Ricardo López 26-10-2023 | Approved by

Document type | Document status

SPDX-FileCopyrightText: 2023 iowLabs
<contacto@iowlabs.com>

SPDX-License-Identifier: CERN-OHL-S-2.0

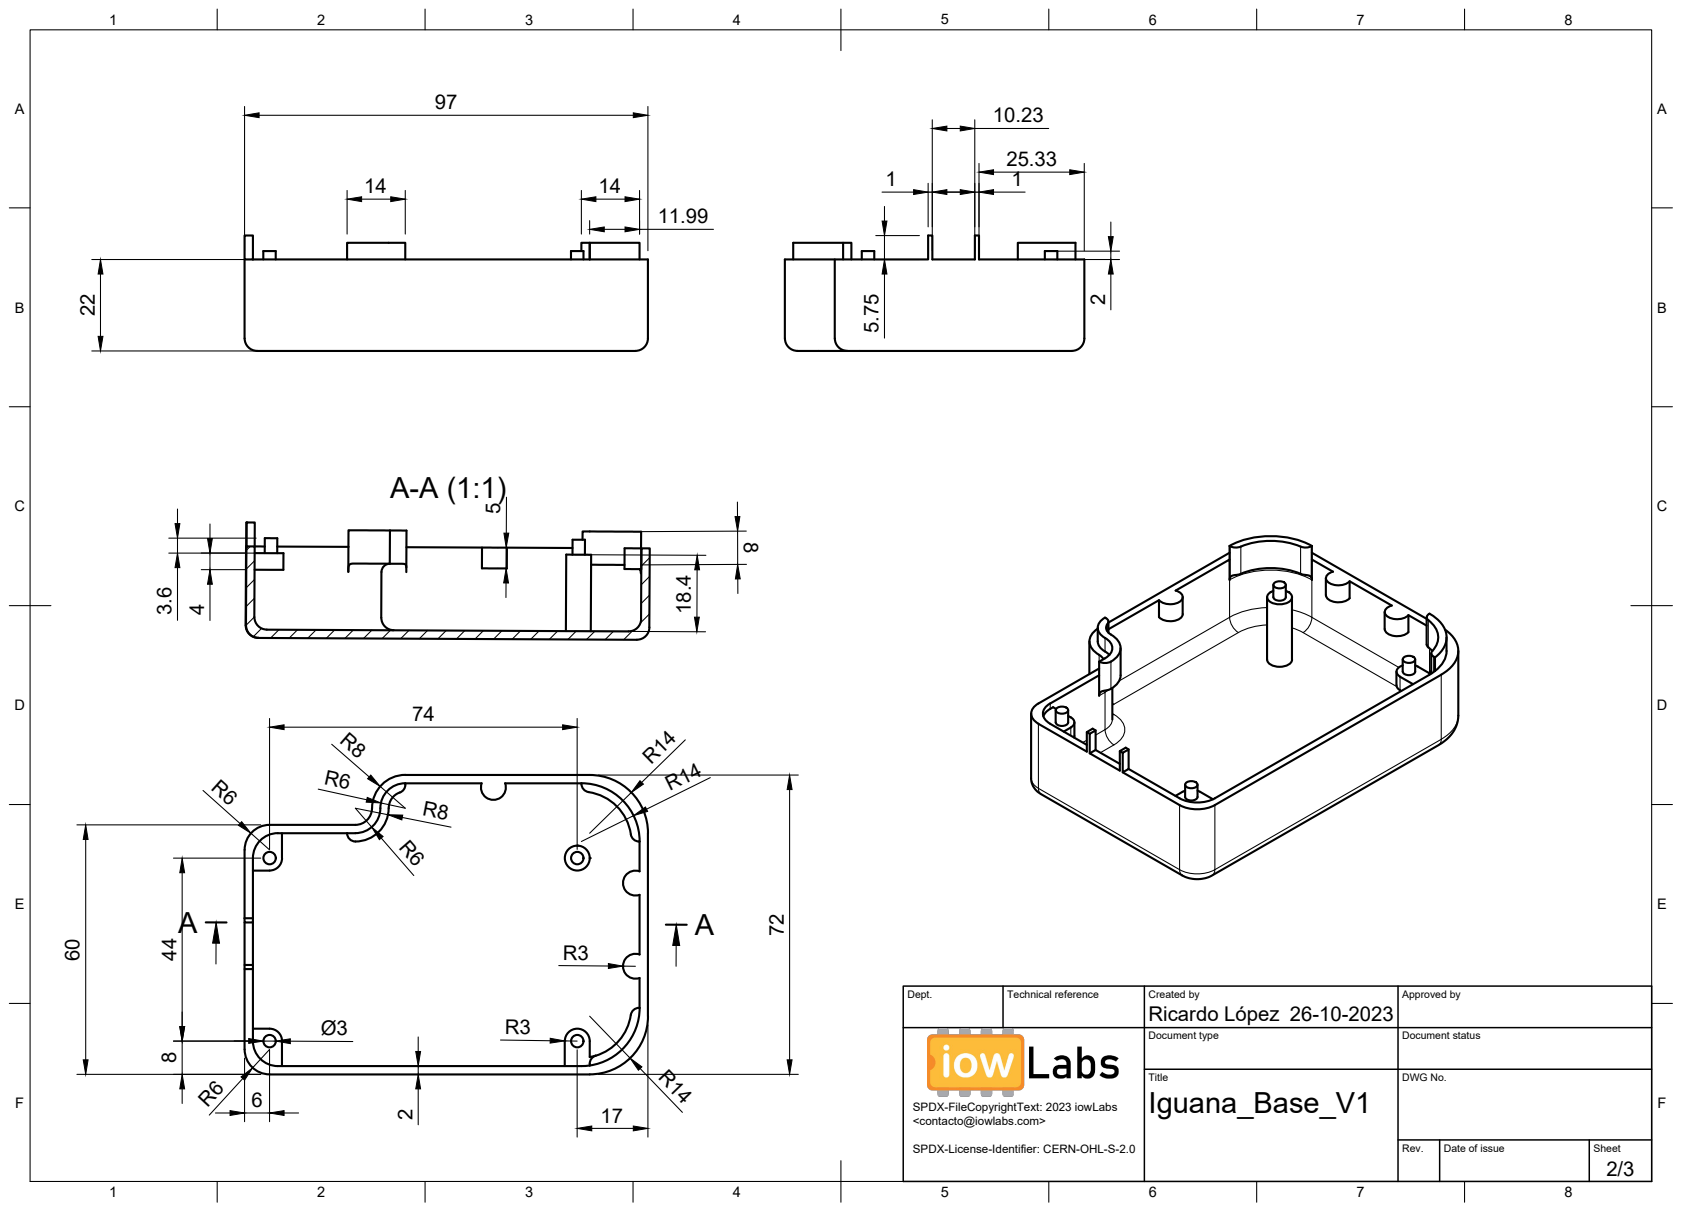
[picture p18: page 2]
Title; DWG No.

Dept. | Technical reference | Created by Ricardo López 26-10-2023 | Approved by

Document type | Document status

SPDX-FileCopyrightText: 2023 iowLabs

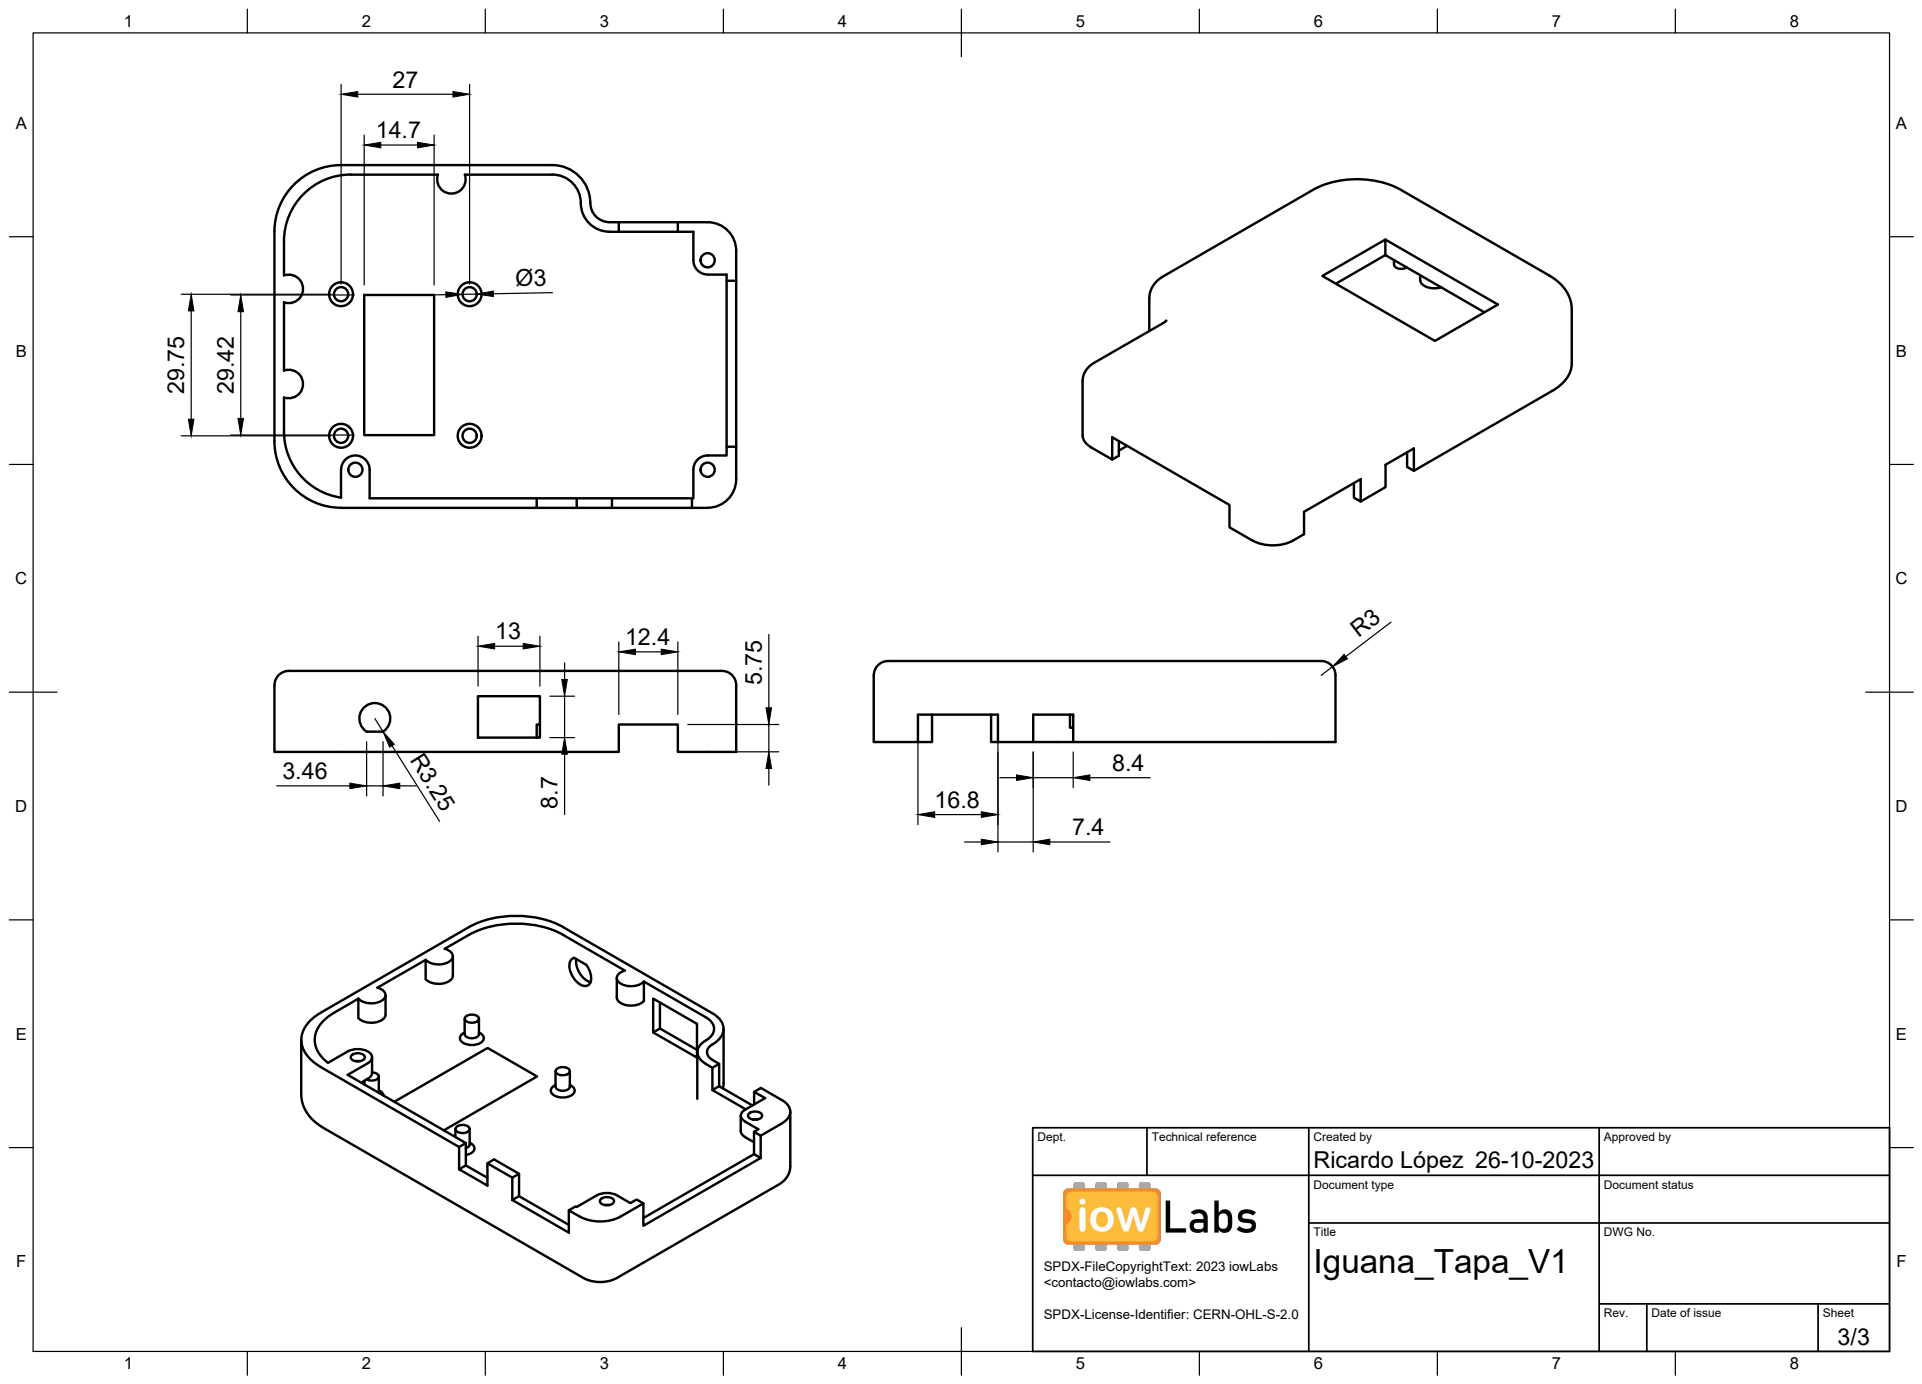
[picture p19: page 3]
Title; DWG No.; Ricardo López 29.75

Dept. | Technical reference | Created by 26-10-2023 | Approved by

Document type | Document status

SPDX-FileCopyrightText: 2023 iowLabs

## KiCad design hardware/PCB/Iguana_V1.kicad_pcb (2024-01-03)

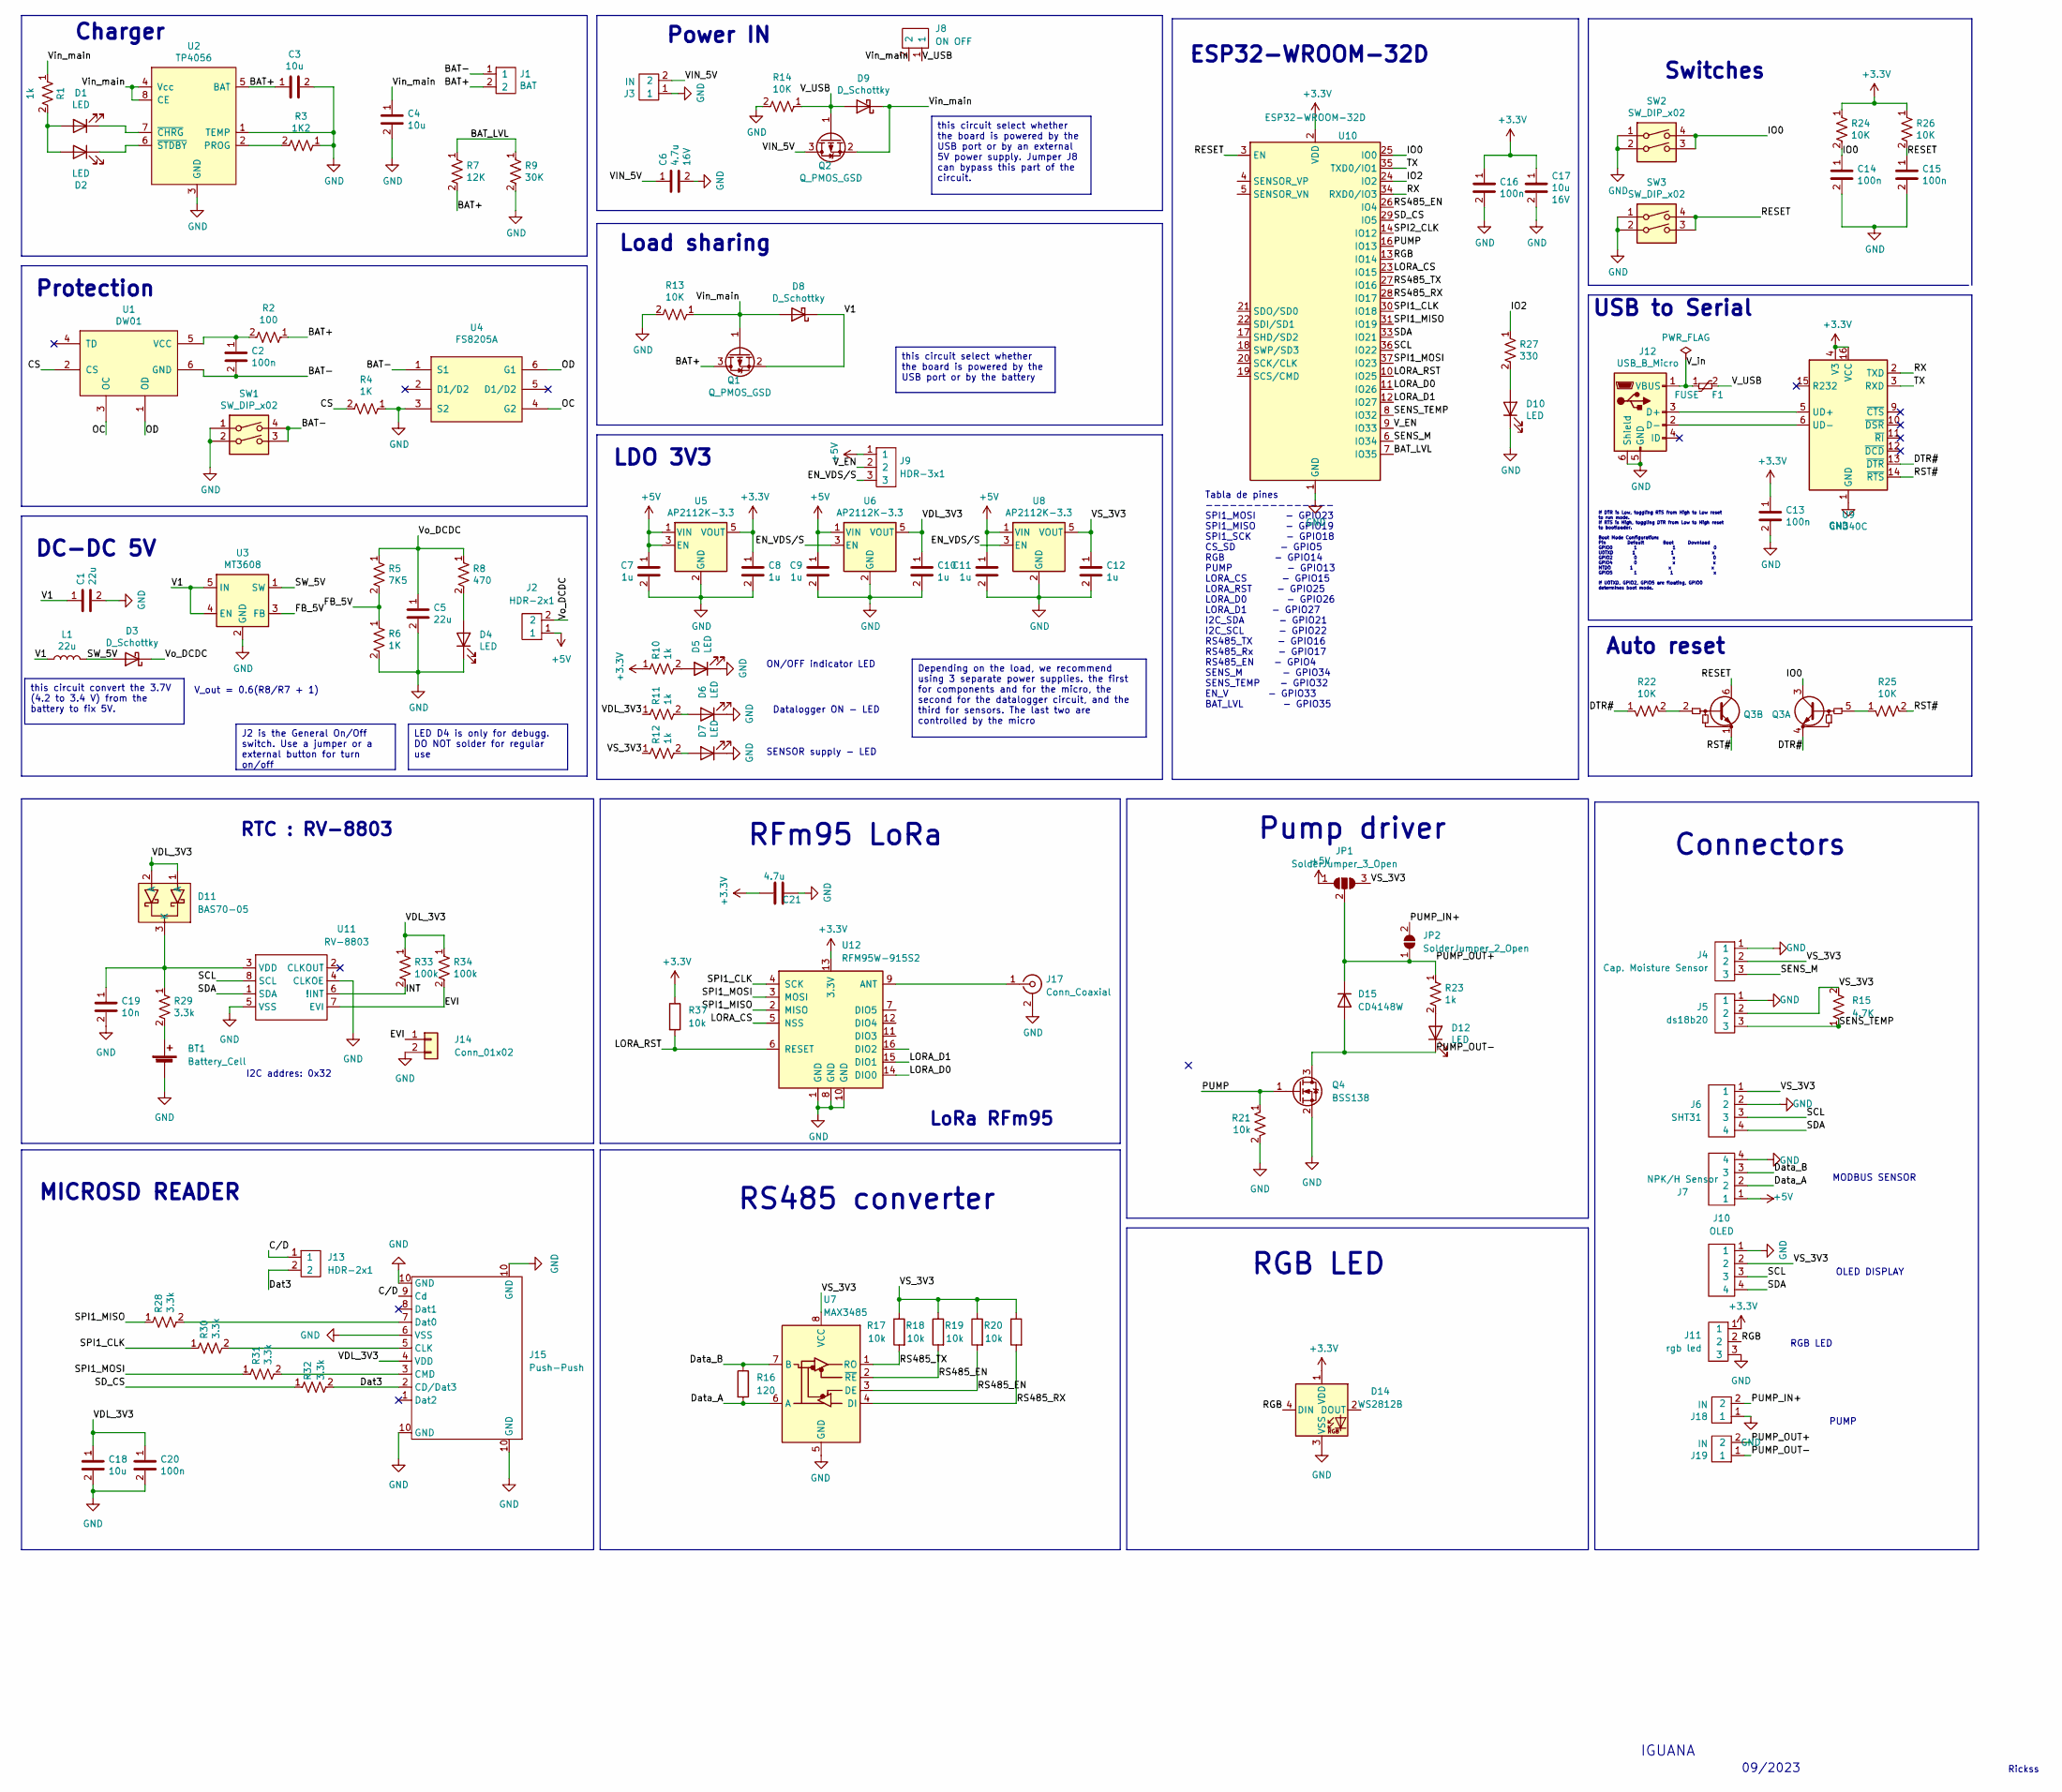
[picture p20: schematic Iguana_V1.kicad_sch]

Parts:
BT1: Battery_Cell; BatteryHolder_Keystone_3000_1x12mm
C1, C5: 22u; C_0805_2012Metric; Voltage rated 16V
C2, C13, C14, C15, C16, C20: 100n; C_0603_1608Metric; Voltage rated 16V
C3, C4, C17, C18: 10u; C_0805_2012Metric; Voltage rated 16V
C6: 4.7u; C_0805_2012Metric; Voltage rated 16V
C7, C8, C9, C10, C11, C12: 1u; C_0603_1608Metric; Voltage rated 16V
C19: 10n; C_0603_1608Metric; Voltage rated 16V
C21: 4.7u; C_0805_2012Metric
D1, D2, D4, D5, D6, D7, D10, D12: LED; LED_0603_1608Metric
D3, D8, D9: D_Schottky; D_SMA
D11: BAS70-05; SOT-23
D14: WS2812B; LED_WS2812B_PLCC4_5.0x5.0mm_P3.2mm
D15: CD4148W; D_0805_2012Metric
F1: FUSE; Fuse_1206_3216Metric
J1: BAT; JST_XH_B2B-XH-A_1x02_P2.50mm_Vertical
J2: HDR-2x1; PinHeader_1x02_P2.54mm_Vertical
J3, J18, J19: IN; JST_XH_B2B-XH-A_1x02_P2.50mm_Vertical
J4: Cap. Moisture Sensor; JST_XH_B3B-XH-A_1x03_P2.50mm_Vertical
J5: ds18b20; JST_XH_B3B-XH-A_1x03_P2.50mm_Vertical
J6: SHT31; JST_XH_B4B-XH-A_1x04_P2.50mm_Vertical
J7: NPK/H Sensor; JST_XH_B4B-XH-A_1x04_P2.50mm_Vertical
J8: ON OFF; SolderJumper-2_P1.3mm_Open_RoundedPad1.0x1.5mm
J9: HDR-3x1; SolderJumper-3_P1.3mm_Open_RoundedPad1.0x1.5mm_NumberLabels
J10: OLED; JST_XH_B4B-XH-A_1x04_P2.50mm_Vertical
J11: rgb led; JST_XH_B3B-XH-A_1x03_P2.50mm_Vertical
J12: USB_B_Micro; USB_Micro-B_Amphenol_10118194_Horizontal
J13: HDR-2x1; SolderJumper-2_P1.3mm_Open_RoundedPad1.0x1.5mm
J14: Conn_01x02; SolderJumper-2_P1.3mm_Open_RoundedPad1.0x1.5mm
J15: microSD_push_push
J17: Conn_Coaxial; U.FL_Molex_MCRF_73412-0110_Vertical
JP1: SolderJumper_3_Open; SolderJumper-3_P1.3mm_Open_RoundedPad1.0x1.5mm
JP2: SolderJumper_2_Open; SolderJumper-2_P1.3mm_Open_RoundedPad1.0x1.5mm
L1: 22u; L_Bourns_SRP7028A_7.3x6.6mm
Q1, Q2: Q_PMOS_GSD; SOT-23
Q3: Q_Dual_NPN_NPN_BRT_E1B1C2E2B2C1; SOT-363_SC-70-6_Handsoldering
Q4: BSS138; SOT-23
R1, R10, R11, R12, R23: 1k; R_0603_1608Metric
R2: 100; R_0603_1608Metric
R3: 1K2; R_0603_1608Metric
R4, R6: 1K; R_0603_1608Metric
R5: 7K5; R_0603_1608Metric
R7: 12K; R_0603_1608Metric
R8: 470; R_0603_1608Metric
R9: 30K; R_0603_1608Metric
R13, R14, R22, R24, R25, R26: 10K; R_0603_1608Metric
R15: 4.7K; R_0603_1608Metric
R16: 120; R_0603_1608Metric
R17, R18, R19, R20, R21, R37: 10k; R_0603_1608Metric
R27: 330; R_0603_1608Metric
R28, R29, R30, R31, R32: 3.3k; R_0603_1608Metric
R33, R34: 100k; R_0603_1608Metric
SW1, SW2, SW3: SW_DIP_x02; SMD_SWITCH
U1: DW01; SOT-23-6
U2: TP4056; TP4056_SOP-8-PP
U3: MT3608; SOT-23-6
U4: FS8205A; SOT-23-6
U5, U6, U8: AP2112K-3.3; SOT-23-5
U7: MAX3485; SOP-8_3.9x4.9mm_P1.27mm
U9: CH340C; SOIC-16_3.9x9.9mm_P1.27mm
U10: ESP32-WROOM-32D; ESP32-WROOM-32
U11: RV-8803; SON-8
U12: RFM95W-915S2; HOPERF_RFM69HW

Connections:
+3V3: C8.1, C13.1, C16.1, C17.1, C21.2, D14.1 (VDD), J11.1, R10.1, R24.1, R26.1, R37.1, U5.5 (VOUT), U9.4 (V3), U9.16 (VCC), U10.2 (VDD), U12.13 (3.3V)
+5V: C7.1, C9.1, C11.1, J2.1, J7.1, J9.1, JP1.1 (A), U5.1 (VIN), U5.3 (EN), U6.1 (VIN), U8.1 (VIN)
/BAT+: C3.1, J1.2, Q1.3 (D), R2.1, R7.2, U2.5 (BAT)
/BAT-: C2.2, J1.1, SW1.3, SW1.4, U1.6 (GND), U4.1 (S1)
/BAT_LVL: R7.1, R9.1, U10.7 (IO35)
/CS: R4.2, U1.2 (CS)
/C/D: J13.1, J15.9 (Cd)
/DTR#: Q3.4 (E1), R22.1, U9.13 (~DTR)
/Dat3: J13.2, J15.2 (CD/Dat3), R32.2
/Data_A: J7.2, R16.2, U7.6 (A)
/Data_B: J7.3, R16.1, U7.7 (B)
/EN_VDS/S: J9.3, U6.3 (EN), U8.3 (EN)
/EVI: J14.1, R34.2, U11.7 (EVI)
/FB_5V: R5.2, R6.1, U3.3 (FB)
/INT: R33.2, U11.6 (!INT)
/IO0: C14.1, Q3.3 (C1), R24.2, SW2.3, SW2.4, U10.25 (IO0)
/IO2: R27.1, U10.24 (IO2)
/LORA_CS: U10.23 (IO15), U12.5 (NSS)
/LORA_D0: U10.11 (IO26), U12.14 (DIO0)
/LORA_D1: U10.12 (IO27), U12.15 (DIO1)
/LORA_RST: R37.2, U10.10 (IO25), U12.6 (RESET)
/OC: U1.3 (OC), U4.4 (G2)
/OD: U1.1 (OD), U4.6 (G1)
/PUMP: Q4.1 (G), R21.1, U10.16 (IO13)
/PUMP_IN+: J18.2, JP2.2 (B)
/PUMP_OUT+: D15.1 (K), J19.2, JP1.2 (C), JP2.1 (A), R23.1
/PUMP_OUT-: D12.1 (K), D15.2 (A), J19.1, Q4.3 (D)
/RESET: C15.1, Q3.6 (C1), R26.2, SW3.3, SW3.4, U10.3 (EN)
/RGB: D14.4 (DIN), J11.2, U10.13 (IO14)
/RS485_EN: R18.2, R19.2, U7.2 (~RE), U7.3 (DE), U10.26 (IO4)
/RS485_RX: R20.2, U7.4 (DI), U10.28 (IO17)
/RS485_TX: R17.2, U7.1 (RO), U10.27 (IO16)
/RST#: Q3.1 (E1), R25.2, U9.14 (~RTS)
/RX: U9.2 (TXD), U10.34 (RXD0/IO3)
/SCL: J6.3, J10.3, U10.36 (IO22), U11.8 (SCL)
/SDA: J6.4, J10.4, U10.33 (IO21), U11.1 (SDA)
/SD_CS: R32.1, U10.29 (IO5)
/SENS_M: J4.3, U10.6 (IO34)
/SENS_TEMP: J5.3, R15.1, U10.8 (IO32)
/SPI1_CLK: R30.1, U10.30 (IO18), U12.4 (SCK)
/SPI1_MISO: R28.1, U10.31 (IO19), U12.2 (MISO)
/SPI1_MOSI: R31.1, U10.37 (IO23), U12.3 (MOSI)
/SPI2_CLK: U10.14 (IO12)
/SW_5V: D3.2 (A), L1.2, U3.1 (SW)
/TX: U9.3 (RXD), U10.35 (TXD0/IO1)
/V1: C1.1, D8.1 (K), L1.1, Q1.2 (S), U3.4 (EN), U3.5 (IN)
/VDL_3V3: C10.1, C18.1, C20.1, D11.1 (A), D11.2 (A), J15.4 (VDD), R11.1, R33.1, R34.1, U6.5 (VOUT)
/VIN_5V: C6.1, J3.2, Q2.3 (D)
/VS_3V3: C12.1, J4.2, J5.2, J6.1, J10.2, JP1.3 (B), R12.1, R15.2, R17.1, R18.1, R19.1, R20.1, U7.8 (VCC), U8.5 (VOUT)
/V_EN: J9.2, U10.9 (IO33)
/V_USB: D9.2 (A), F1.2, J8.1, Q2.1 (G), R14.1
/V_in: F1.1, J12.1 (VBUS)
/Vin_main: C4.1, D8.2 (A), D9.1 (K), J8.2, Q1.1 (G), Q2.2 (S), R1.1, R13.1, U2.4 (Vcc), U2.8 (CE)
/Vo_DCDC: C5.1, D3.1 (K), J2.2, R5.1, R8.1
GND: BT1.2 (-), C1.2, C3.2, C4.2, C5.2, C6.2, C7.2, C8.2, C9.2, C10.2, C11.2, C12.2, C13.2, C14.2, C15.2, C16.2, C17.2, C18.2, C19.2, C20.2, C21.1, D4.1 (K), D5.1 (K), D6.1 (K), D7.1 (K), D10.1 (K), D14.3 (VSS), J3.1, J4.1, J5.1, J6.2, J7.4, J10.1, J11.3, J12.5 (GND), J12.6 (Shield), J14.2, J15.6 (VSS), J15.10 (GND), J17.2 (Ext), J18.1, Q4.2 (S), R3.1, R4.1, R6.2, R9.2, R13.2, R14.2, R21.2, SW1.1, SW1.2, SW2.1, SW2.2, SW3.1, SW3.2, U2.1 (TEMP), U2.3 (GND), U3.2 (GND), U4.3 (S2), U5.2 (GND), U6.2 (GND), U7.5 (GND), U8.2 (GND), U9.1 (GND), U10.1 (GND), U10.15 (GND), U10.38 (GND), U10.39 (GND), U11.4 (CLKOE), U11.5 (VSS), U12.1 (GND), U12.8 (GND), U12.10 (GND)
unnamed: BT1.1 (+), R29.2
unnamed: D1.2 (A), D2.2 (A), R1.2
unnamed: D1.1 (K), U2.7 (~CHRG)
unnamed: D2.1 (K), U2.6 (~STDBY)
unnamed: D4.2 (A), R8.2
unnamed: D5.2 (A), R10.2
unnamed: D6.2 (A), R11.2
unnamed: D7.2 (A), R12.2
unnamed: D10.2 (A), R27.2
unnamed: C19.1, D11.3 (K), R29.1, U11.3 (VDD)
unnamed: D12.2 (A), R23.2
unnamed: J12.3 (D+), U9.5 (UD+)
unnamed: J12.2 (D-), U9.6 (UD-)
unnamed: J15.5 (CLK), R30.2
unnamed: J15.3 (CMD), R31.2
unnamed: J15.7 (Dat0), R28.2
unnamed: J17.1 (In), U12.9 (ANT)
unnamed: Q3.5 (B1), R25.1
unnamed: Q3.2 (B1), R22.2
unnamed: C2.1, R2.2, U1.5 (VCC)
unnamed: R3.2, U2.2 (PROG)

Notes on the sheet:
this circuit select whether the board is powered by the USB port or by the battery
this circuit select whether the board is powered by the USB port or by an external 5V power supply. Jumper J8 can bypass this part of the circuit.
LED D4 is only for debugg. DO NOT solder for regular use
this circuit convert the 3.7V (4.2 to 3.4 V) from the battery to fix 5V.
J2 is the General On/Off switch. Use a jumper or a external button for turn on/off
Depending on the load, we recommend using 3 separate power supplies. the first for components and for the micro, the second for the datalogger circuit, and the third for sensors. The last two are controlled by the micro
I2C addres: 0x32
DC-DC 5V
Tabla de pines ---------------- SPI1_MOSI - GPIO23 SPI1_MISO - GPIO19 SPI1_SCK - GPIO18 CS_SD - GPIO5 RGB - GPIO14 PUMP - GPIO13 LORA_CS - GPIO15 LORA_RST - GPIO25 LORA_D0 - GPIO26 LORA_D1 - GPIO27 I2C_SDA - GPIO21 I2C_SCL - GPIO22 RS485_TX - GPIO16 RS485_Rx - GPIO17 RS485_EN - GPIO4 SENS_M - GPIO3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
ON/OFF indicator LED
Power IN
RTC : RV-8803
Auto reset
USB to Serial
Connectors
PUMP
IGUANA
MICROSD READER
09/2023
If DTR is Low, toggling RTS from High to Low reset to run mode. If RTS is High, toggling DTR from Low to High reset to bootloader. Boot Mode Configuration: Pin Default Boot Download GPIO0 1 1 0 U0TXD 1 1 x GPIO2 0 x 0 GPIO4 0 x x MTDO 1 x x GPIO5 1 1 x If U0TXD, GPIO2, GPIO5 are floating, GPIO0 det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
RS485 converter
Load sharing
ESP32-WROOM-32D
RFm95 LoRa
Pump driver
Charger
Switches
LoRa RFm95
RGB LED
Rickss
V_out = 0.6(R8/R7 + 1)
SENSOR supply - LED
Protection
Datalogger ON - LED
OLED DISPLAY
MODBUS SENSOR
LDO 3V3

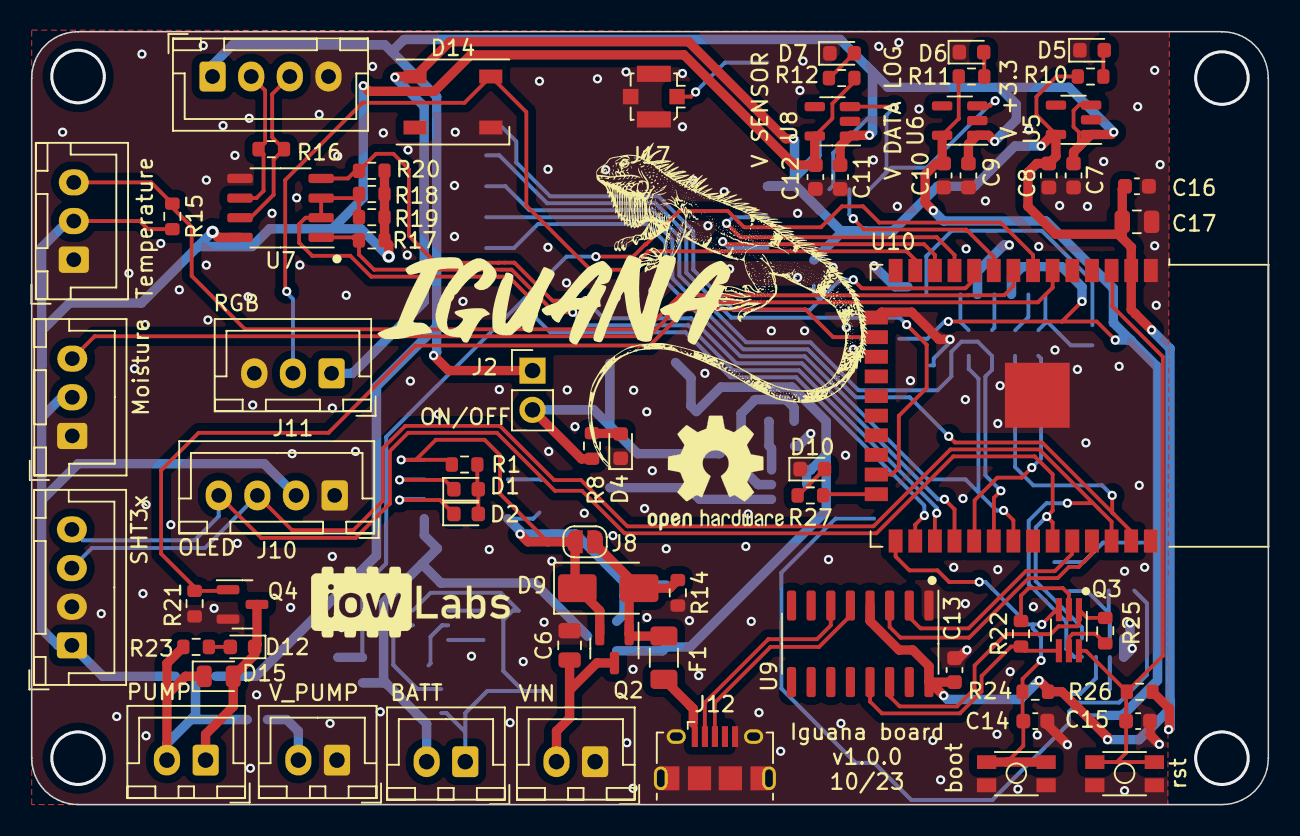
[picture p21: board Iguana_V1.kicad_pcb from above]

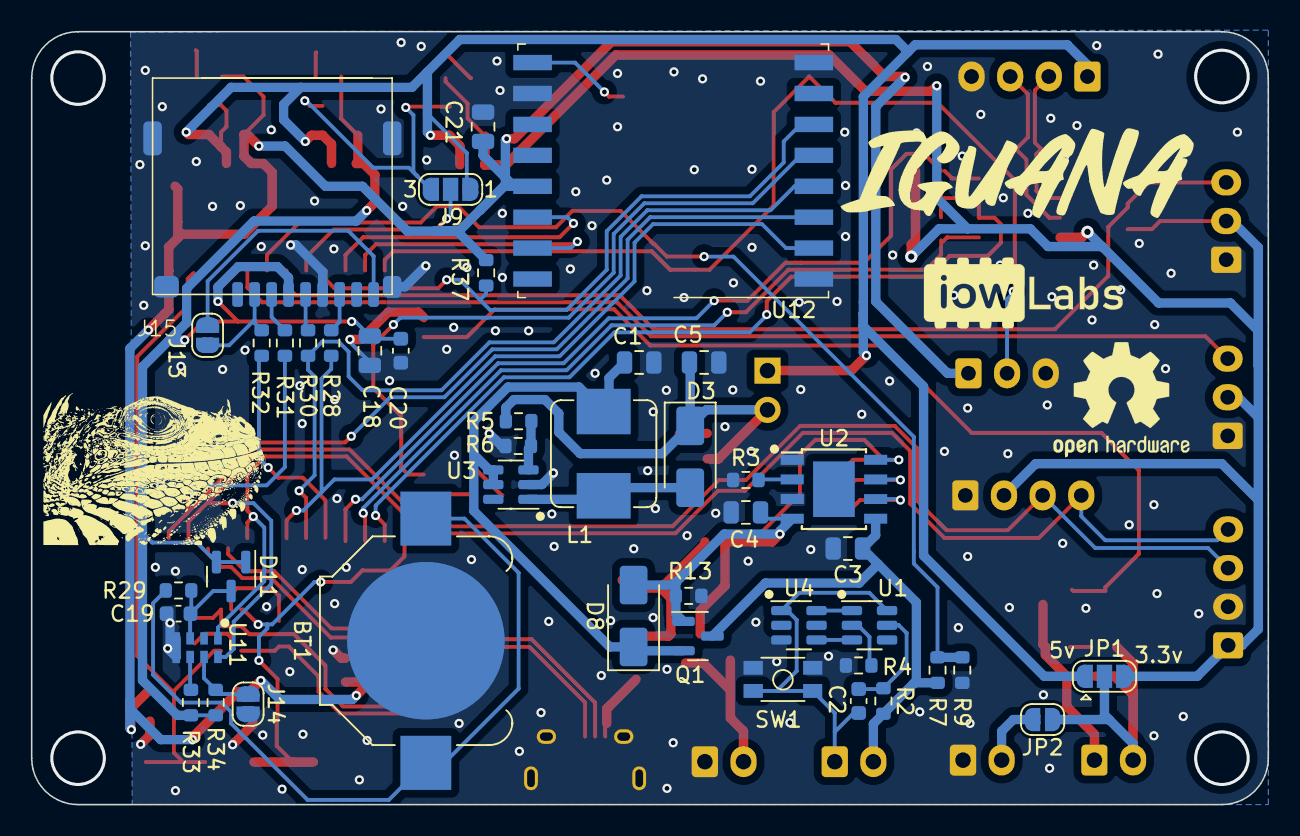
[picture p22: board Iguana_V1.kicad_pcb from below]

Board: 2 copper layers, 80.0 x 50.0 mm, 112 parts (44 on the bottom side), 75 nets.

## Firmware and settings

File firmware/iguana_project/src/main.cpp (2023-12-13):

/*
# SPDX-FileCopyrightText: 2023 iowlabs <contacto@iowlabs.com>
#
# SPDX-License-Identifier: GPL-3.0-or-later.txt
*/

/*
Project: Iguana
DESCRIPTION: This code is for Iguana sensor station for small agriculture.
It features both temperature and humidity sensors to monitor 

Last Author: Rickss

Features: Capacitive Soil Moisture Sensor, DS18B20 waterproof temperature sensor 
and SHT31 Temperature & Humidity Sensor. 1'3 OLED Screen.

Connections (USED PIN MAP):
  -----------------------------

Comunication:
  -----------------------------

LIBS:
	sparkfun/SparkFun Qwiic RTC RV8803 Arduino Library @ ^1.2.8
	paulstoffregen/OneWire@^2.3.7
	milesburton/DallasTemperature@^3.11.0
	adafruit/Adafruit SHT31 Library@^2.2.2
	adafruit/Adafruit BusIO@^1.14.3
	adafruit/Adafruit Unified Sensor@^1.1.13
	bblanchon/ArduinoJson@^6.21.3
	adafruit/Adafruit SH110X @ ^2.1.8
    adafruit/Adafruit GFX Library @ ^1.11.5
	fastled/FastLED@^3.6.0
	sandeepmistry/LoRa @ ^0.8.0
	hieromon/AutoConnect @ ^1.4.2

TODOLIST:
-	EXAMPLES FILES
-	CHECK STATUS and connectivity
- 	HANDLE ERRORS
- 	ADD RGB FEATUREs
- 	ADD PUMP Features
-   ADD AUTOMATIC Functions
-   SET SAMPLE TIME options
-   ADD TIMERs
-	less RGB brightness
*/

#include <Arduino.h>
#include "iowIguana.h"

iowIguana iguana = iowIguana();
uint8_t status;
String output;

void setup()
{
	Serial.begin(115200);
  	iguana.activateSTH();
  	iguana.activateSoilTemp();
  	iguana.activateSoilMoisture();
	status = iguana.begin();
	printlnd(status);

  	delay(200);

  	iguana.iowLogo();
  	delay(3000);
  	iguana.showLogo();
  	delay(3000);

	Serial.println("Setup Ready");
}

void loop()
{
  iguana.readSensors();
  output = iguana.pubData();
  Serial.println(output);
  //iguana.saveData();
  iguana.showData(2500);

}

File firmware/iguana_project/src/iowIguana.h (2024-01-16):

/*
# SPDX-FileCopyrightText: 2023 iowlabs <contacto@iowlabs.com>
#
# SPDX-License-Identifier: GPL-3.0-or-later.txt
*/

#ifndef __IOWIGUANA__
#define __IOWIGUANA__

#include <Arduino.h>
#include <Wire.h>
#include <SPI.h>
#include "Adafruit_SHT31.h"
#include <Adafruit_SH110X.h>
#include <Adafruit_GFX.h>
#include <SparkFun_RV8803.h>
#include <DallasTemperature.h>
#include <OneWire.h>
#include "uSD_iow.h"
#include <FastLED.h>
#include <ArduinoJson.h>
#include <LoRa.h>
#include <WiFi.h>
#include <HTTPClient.h>
#include <HTTPUpdate.h>
#include "WiFiClientSecure.h"
//#include "cert.h"
//#include <SoftwareSerial.h>



/*-------PINs OF IGUANA BOARD------*/
#define LED          2 // on board led
#define I2C_SCL      22
#define I2C_SDA      21

#define SD_CS        5 //VSPI
#define SD_MISO      19
#define SD_MOSI      23
#define SD_CLK       18

#define RFM_CS       15
#define RFM_RST      25
#define RFM_DIO0     26
#define RFM_DIO1     27

#define RS485_TX 	 16 //HARDWARE SERIAL 2
#define RS485_RX     17 //HARDWARE SERIAL 2
#define RS485_EN     4
#define V_EN		 33

#define PUMP       	13
#define RGB        	14
#define SENS_TEMP  	32
#define SENS_M    	34
#define BAT_LVL    	35


#define DISPLAY_ADDRESS 	0x3C
#define SCREEN_WIDTH 		128 // OLED display width, in pixels
#define SCREEN_HEIGHT 		64 // OLED display height, in pixels
#define OLED_RESET     		-1 // Reset pin # (or -1 if sharing Arduino reset pin)

#define ID              "n06_ota"
#define RESPONSE_OK     "OK"
#define RESPONSE_ERROR  "ERROR"
#define FILE_NAME       "/Iguana_log.txt"

#define STATUS_OK     0
#define STATUS_ERROR  1
#define ERROR_SD      0b00000001
#define ERROR_RTC     0b00000010
#define ERROR_OLED    0b00000100
#define ERROR_LORA    0b00001000

#define N_AVG_SAMPLES 			100

//CALIBRATION PARAMETERS
#define MOISTURE_AIR_VALUE 		2468
#define MOISTURE_WATER_VALUE	986

#define SERIAL_RS485 Serial2


#define RS485_BR 	 4800

#define DEBUG     1

//Macros for enable serial prints
#if DEBUG
#define printd(s) {Serial.print((s));}
#define printlnd(s) {Serial.println((s));}
#else
#define printd(s)
#define printlnd(s)
#endif


// OTAUPDATE

#define URL_fw_Bin "https://raw.githubusercontent.com/Iowlabs/Iguana/main/firmware/OTA_bin_file/firmware.bin"




const unsigned char logo_iowlabs [] PROGMEM =
{
	0x00, 0x00, 0x00, 0x00, 0x00, 0x00, 0x00, 0x00, 0x00, 0x00, 0x00, 0x00, 0x00, 0x00, 0x00, 0x00,
	0x00, 0x00, 0x00, 0x00, 0x00, 0x00, 0x00, 0x00, 0x00, 0x00, 0x00, 0x00, 0x00, 0x00, 0x00, 0x00,
	0x00, 0x00, 0x00, 0x00, 0x00, 0x00, 0x00, 0x00, 0x00, 0x00, 0x00, 0x00, 0x00, 0x00, 0x00, 0x00,
	0x00, 0x00, 0x00, 0x00, 0x00, 0x00, 0x00, 0x00, 0x00, 0x00, 0x00, 0x00, 0x00, 0x00, 0x00, 0x00,
	0x00, 0x00, 0x00, 0x00, 0x00, 0x00, 0x00, 0x00, 0x00, 0x00, 0x00, 0x00, 0x00, 0x00, 0x00, 0x00,
	0x00, 0x00, 0x00, 0x00, 0x00, 0x00, 0x00, 0x00, 0x00, 0x00, 0x00, 0x00, 0x00, 0x00, 0x00, 0x00,
	0x00, 0x00, 0x00, 0x00, 0x00, 0x00, 0x00, 0x00, 0x00, 0x00, 0x00, 0x00, 0x00, 0x00, 0x00, 0x00,
	0x00, 0x00, 0x00, 0x00, 0x00, 0x00, 0x00, 0x00, 0x00, 0x00, 0x00, 0x00, 0x00, 0x00, 0x00, 0x00,
	0x00, 0x00, 0x00, 0x00, 0x00, 0x00, 0x00, 0x00, 0x00, 0x00, 0x00, 0x00, 0x00, 0x00, 0x00, 0x00,
	0x00, 0x00, 0x00, 0x00, 0x00, 0x00, 0x00, 0x00, 0x00, 0x00, 0x00, 0x00, 0x00, 0x00, 0x00, 0x00,
	0x01, 0xfc, 0x03, 0xf0, 0x0f, 0xc0, 0x3f, 0x80, 0x00, 0x00, 0x00, 0x00, 0x00, 0x00, 0x00, 0x00,
	0x01, 0xfc, 0x07, 0xf8, 0x0f, 0xe0, 0x3f, 0x80, 0x00, 0x00, 0x00, 0x00, 0x00, 0x00, 0x00, 0x00,
	0x01, 0xfc, 0x07, 0xf8, 0x1f, 0xe0, 0x3f, 0x80, 0x00, 0x00, 0x00, 0x00, 0x00, 0x00, 0x00, 0x00,
	0x01, 0xfc, 0x07, 0xf8, 0x1f, 0xe0, 0x3f, 0x80, 0x00, 0x00, 0x00, 0x00, 0x00, 0x00, 0x00, 0x00,
	0x3f, 0xff, 0xff, 0xff, 0xff, 0xff, 0xff, 0xfc, 0x00, 0x00, 0x00, 0x00, 0x00, 0x00, 0x00, 0x00,
	0x7f, 0xff, 0xff, 0xff, 0xff, 0xff, 0xff, 0xff, 0x00, 0x00, 0x00, 0x00, 0x00, 0x00, 0x00, 0x00,
	0xff, 0xff, 0xff, 0xff, 0xff, 0xff, 0xff, 0xff, 0x00, 0x00, 0x00, 0x00, 0x00, 0x00, 0x00, 0x00,
	0xff, 0xff, 0xff, 0xff, 0xff, 0xff, 0xff, 0xff, 0x00, 0x00, 0x00, 0x00, 0x00, 0x00, 0x00, 0x00,
	0xff, 0xff, 0xff, 0xff, 0xff, 0xff, 0xff, 0xff, 0x00, 0x00, 0x00, 0x00, 0x00, 0x00, 0x00, 0x00,
	0xff, 0xff, 0xff, 0xff, 0xff, 0xff, 0xff, 0xff, 0x00, 0x00, 0x00, 0x00, 0x00, 0x00, 0x00, 0x00,
	0xff, 0xff, 0xff, 0xff, 0xff, 0xff, 0xff, 0xff, 0x00, 0x00, 0x00, 0x00, 0x00, 0x00, 0x00, 0x00,
	0xff, 0xe3, 0xff, 0xff, 0xff, 0xff, 0xff, 0xff, 0x00, 0x00, 0x00, 0x00, 0x00, 0x00, 0x00, 0x00,
	0xff, 0xe1, 0xff, 0xff, 0xff, 0xff, 0xff, 0xff, 0x1e, 0x00, 0x00, 0x00, 0x1e, 0x00, 0x00, 0x00,
	0xff, 0xe3, 0xff, 0xff, 0xff, 0xff, 0xff, 0xff, 0x1e, 0x00, 0x00, 0x00, 0x1e, 0x00, 0x00, 0x00,
	0xff, 0xf7, 0xff, 0xff, 0xff, 0xff, 0xff, 0xff, 0x1e, 0x00, 0x00, 0x00, 0x1e, 0x00, 0x00, 0x00,
	0xff, 0xff, 0xff, 0xff, 0xff, 0xff, 0xff, 0xff, 0x1e, 0x00, 0x00, 0x00, 0x1e, 0x00, 0x00, 0x00,
	0xff, 0xff, 0xff, 0xff, 0xff, 0xff, 0xff, 0xff, 0x1e, 0x00, 0x00, 0x00, 0x1e, 0x00, 0x00, 0x00,
	0xff, 0xe3, 0xfc, 0x07, 0xe3, 0xf0, 0xfc, 0x7f, 0x1e, 0x00, 0x00, 0xc0, 0x1e, 0x60, 0x01, 0xc0,
	0xff, 0xe1, 0xf0, 0x01, 0xe3, 0xf0, 0xfc, 0x7f, 0x1e, 0x00, 0x07, 0xf8, 0x1f, 0xf8, 0x0f, 0xf8,
	0xff, 0xe1, 0xe0, 0x40, 0xe1, 0xf0, 0x7c, 0x7f, 0x1e, 0x00, 0x0f, 0xfc, 0x1f, 0xfc, 0x1f, 0xfe,
	0xff, 0xe1, 0xe1, 0xf0, 0xf1, 0xe0, 0x78, 0x7f, 0x1e, 0x00, 0x0f, 0xfe, 0x1f, 0xfe, 0x1f, 0xfe,
	0xff, 0xe1, 0xc3, 0xf8, 0x71, 0xe0, 0x78, 0xff, 0x1e, 0x00, 0x06, 0x1e, 0x1f, 0x1e, 0x3e, 0x1c,
	0xff, 0xe1, 0xc3, 0xf8, 0x70, 0xe0, 0x38, 0xff, 0x1e, 0x00, 0x00, 0x0e, 0x1e, 0x0e, 0x3c, 0x00,
	0xff, 0xe1, 0xc3, 0xf8, 0x78, 0xc2, 0x30, 0xff, 0x1e, 0x00, 0x00, 0x0e, 0x1e, 0x0e, 0x3f, 0x00,
	0xff, 0xe1, 0xc3, 0xf8, 0x78, 0xc6, 0x31, 0xff, 0x1e, 0x00, 0x07, 0xfe, 0x1e, 0x0e, 0x1f, 0xf8,
	0xff, 0xe1, 0xc3, 0xf8, 0x78, 0x46, 0x31, 0xff, 0x1e, 0x00, 0x0f, 0xfe, 0x1e, 0x0e, 0x1f, 0xfc,
	0xff, 0xe1, 0xc3, 0xf8, 0x7c, 0x47, 0x01, 0xff, 0x1e, 0x00, 0x1f, 0xfe, 0x1e, 0x0e, 0x07, 0xfe,
	0xff, 0xe1, 0xc3, 0xf8, 0x7c, 0x0f, 0x03, 0xff, 0x1e, 0x00, 0x1e, 0x0e, 0x1e, 0x0e, 0x00, 0x1e,
	0xff, 0xe1, 0xe1, 0xf0, 0xfc, 0x0f, 0x03, 0xff, 0x1e, 0x00, 0x1c, 0x0e, 0x1e, 0x0e, 0x10, 0x1e,
	0xff, 0xe1, 0xe0, 0x40, 0xfe, 0x0f, 0x83, 0xff, 0x1e, 0x00, 0x1e, 0x0e, 0x1e, 0x1e, 0x1c, 0x1e,
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
};
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

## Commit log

2023-08-29 Firmware Creation
    Firmare to read humidity and temperature for soils and ambient.
2023-09-11 PCB Updated
    [Iguana_V1.kicad_pcb, Iguana_V1.kicad_sch]
2023-09-23 adding relay and working on pcb
    [Iguana_V1.kicad_pcb, Iguana_V1.kicad_sch]
2023-09-29 replace relay. working on pcb
    [Iguana_V1.kicad_pcb, Iguana_V1.kicad_sch]
2023-09-29 pcb almost ready
    [Iguana_V1.kicad_pcb]
2023-10-03 pcb finished
    [Iguana_V1.kicad_pcb, Iguana_V1.kicad_sch]
2023-10-14 Added circles on edgecut.
    Added circles where the drill holes were suppossed to go for the .step file be created with holes.
2023-10-16 pcb minor changes
    [Iguana_V1.kicad_pcb, Iguana_V1.kicad_sch]
2023-10-26 starting firmware
    [Iguana_V1-B_Cu.gbl, Iguana_V1-B_Mask.gbs, Iguana_V1-B_Paste.gbp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]
2023-10-26 3D Files Uploaded
    V1 Iguana Case Files Uploaded
    [Iguana_Case_V1.3mf, Iguana_Case_V1.f3z, Iguana_Case_V1.step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]
2023-11-02 Firmware Update
    Test done, Oled don't work, fix that
    [iowIguana.h, main.cpp]
2023-11-06 organizing the schematic. firmware lib v1 working.
    [Iguana_V1.kicad_pcb, Iguana_V1.kicad_sch]
2023-11-13 3D Files Uploaded
    [Iguana_Case_Final v2.f3z, Iguana_Case_Final v2.step, Iguana_Case_Final v2.stl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]
2023-11-14 workng on readme
    [Iguana_Case_Final v2.f3z, Iguana_Case_Final v2.step, Iguana_Case_Final v2.stl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]
2023-11-15 adding structure images
    [Iguana_Case_Final v2.f3z, Iguana_Case_Final v2.step, Iguana_Case_Final v2.stl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]
2024-01-03 testing modbus code
    [Iguana_V1.kicad_pcb]
2024-01-03 arreglo de medicion sensor RS485
    [iowIguana_cambioRS485.cpp, iowIguana_cambioRS485.h]
2024-01-04 se agrega repo con .bin para OTA UPDATE
2024-01-04 actualizacion de firmware. Se incluye OTA update con link de github
2024-01-04 se agregan librerias para solucionar bug de OTA cuando se cae la wifi en mitad del update
    [OTA_update_mqtt.cpp, iowIguana.cpp, iowIguana.h]
2024-01-10 Implementacion de Deep Sleep y MQTT en Iguana
2024-01-23 integracion de deepsleep y mqtt con comandos. Falta integrar bien OTA con aws por los certificados y mejorar el sistema de comandos para incluir funcionalidades de cambiar el tiempo de deep sleep u o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
2024-01-31 3D Model Update
    Structural issues noticed when assembly, fixed them on the 3D Model
    [Iguana_Case_Final v3.step, Iguana_Case_V1.f3z]
